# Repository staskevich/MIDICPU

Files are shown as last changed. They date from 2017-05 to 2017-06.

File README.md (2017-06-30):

MIDI CPU

copyright John Staskevich, 2017

john@codeandcopper.com

This work is licensed under a Creative Commons Attribution 4.0 International License.
http://creativecommons.org/licenses/by/4.0/

HARDWARE:

Eagle 6 board layout files and OpenOffice BOMs are included in the pcb/ folder. There is also a design for a "programming cradle" that mates the test points on the MIDI CPU with a PIC programmer for ICSP.

A public CircuitHub project is available for on-demand manufacturing:
https://circuithub.com/projects/CodeandCopper1/MIDICPU

FIRMWARE:

The code in the src/ folder can be assembled for the PIC16F887 device using Microchip's MPASM assembler. Selected firmware images are located in the hex/ folder. Firmware patches in SysEx format are in the syx/ folder.

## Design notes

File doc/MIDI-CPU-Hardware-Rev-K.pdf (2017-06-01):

Highly Liquid | MIDI CPU Hardware Rev K

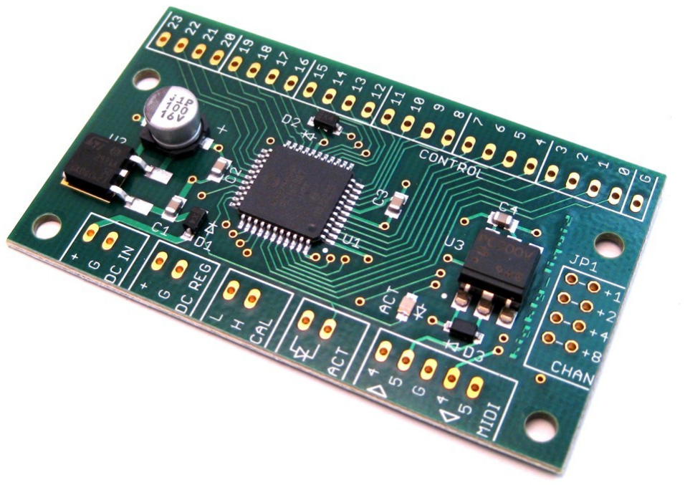
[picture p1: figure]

© 2010 Sonarcana LLC | Page 1 / 18

## MIDI CPU

## Hardware Revision K

## User Manual

### Updated 2010-09-08

Additional documentation available at: http://highlyliquid.com/support/

## Table of Contents

## 1.0 Important Safety Information

To prevent damage to the MIDI CPU and connected devices, and to prevent personal injury:
- Use an appropriate power source. Incorrect supply voltage could cause the MIDI CPU to overheat and/or cause the on-board electrolytic capacitor to explode.
- Do not connect signals which exceed the specified electrical maximums of the MIDI CPU.
- Do not exceed the specified maximum current load of MIDI CPU outputs. Overloading may damage the MIDI CPU and cause excess power consumption from the power supply.
- Take reasonable static control precautions when handling. The MIDI CPU contains ESD-sensitive parts.

## 2.0 Feature Diagram

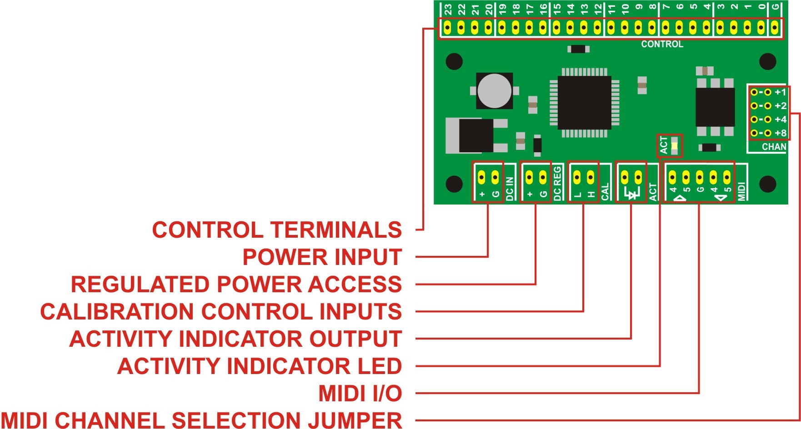
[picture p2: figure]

- Control Terminals: Switches, potentiometers, encoders, control signals or indicator LEDs are connected here. See Control Wiring.
- Power Input: DC power input. See Power Supply.
- Regulated Power Access: Output from on-board voltage regulator. See Voltage Regulation.
- Calibration Control Inputs: See MIDI CPU Firmware User Manual.
- Activity Indicator Output: Can be used to control a remote activity indicator LED. See Remote Power & Activity LED Wiring.
- Activity Indicator LED: See MIDI CPU Firmware User Manual.
- MIDI I/O: Standard MIDI IN and MIDI OUT ports. See MIDI Wiring.
- MIDI CHANNEL SELECTION JUMPER: Optionally specifies the channel for MIDI input and output. See MIDI Channel Selection Jumper.

## 3.0 Mechanical Drawing

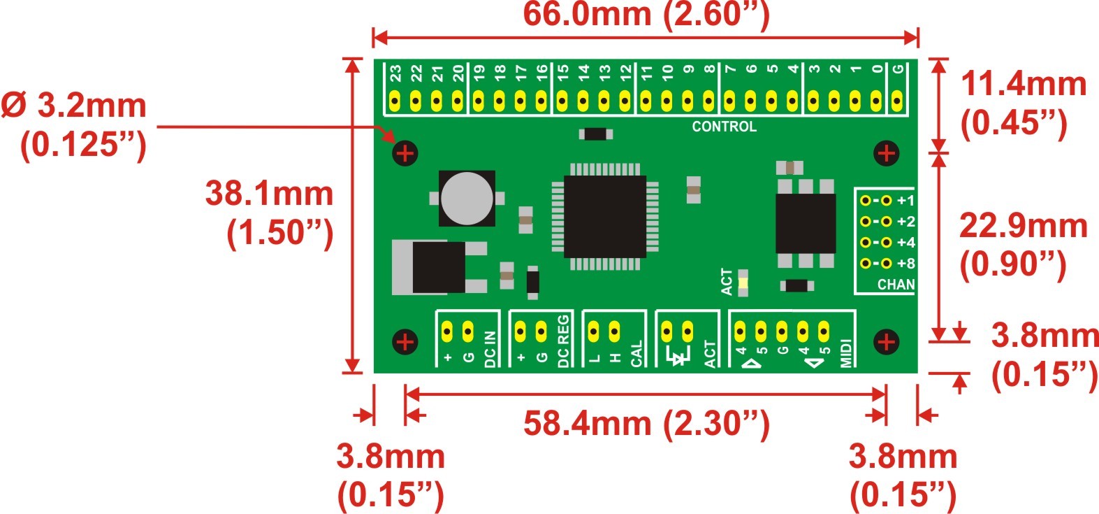
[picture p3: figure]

## 4.0 Power Supply

To operate, the MIDI CPU must be connected to a battery or other DC power supply. A “wall adapter” supply with appropriate specifications may be used. VSUPPLY refers to the output voltage of the power supply.

### 4.1 Specifications

- VSUPPLY maximum: 12VDC
- VSUPPLY minimum: 3.3VDC*
- Power supply current capacity: 150mA or greater
*Note: If VSUPPLY is less than 5.3V, the MIDI OUT signal generated by the MIDI CPU may not be strong enough to trigger some receiving devices.

### 4.2 Wiring

Wire the battery or power supply to the MIDI CPU as shown in Figure 4.1. All MIDI CPU terminals marked “G” are MIDI CPU ground.

### 4.3 Voltage Regulation

The MIDI CPU has an on-board voltage regulator. The output of the regulator powers the on-board components and is accessible via the “DC REG” terminals. Regulator output voltage (VREG) is the lesser of 5V or (VSUPPLY − 0.3V).
Figure 4.1: Power Supply Wiring

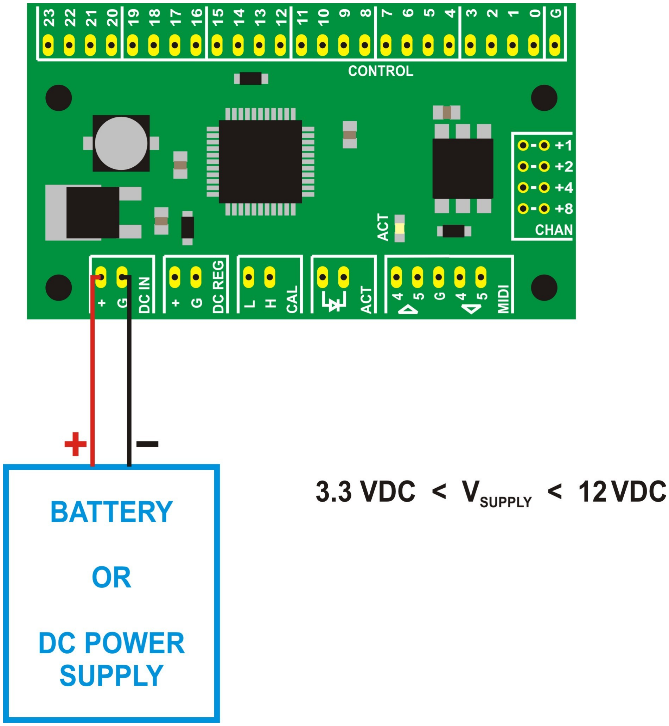
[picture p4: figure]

## 5.0 MIDI Wiring

The MIDI CPU features both a MIDI IN and MIDI OUT port. Figure 5.1 shows the typical connection to other MIDI devices.
The MIDI standard specifies a 5-position DIN connector. Figure 5.2 shows MIDI receptacle pin numbering. The MIDI signal is carried by pins 4 & 5. Pin 2 is connected to ground at the OUT or THRU side of the MIDI link, and is left unconnected at the IN side of the link. Pins 1 & 3 are unused. Connector pin numbers are marked on the MIDI CPU. See Figure 5.3.
Multiple MIDI CPU units can be chained together. For this purpose, MIDI connectors can be bypassed: the OUT port of one unit can be wired directly to the IN port of the next device in the chain. See Figure 5.4.

Figure 5.1: MIDI IN/OUT

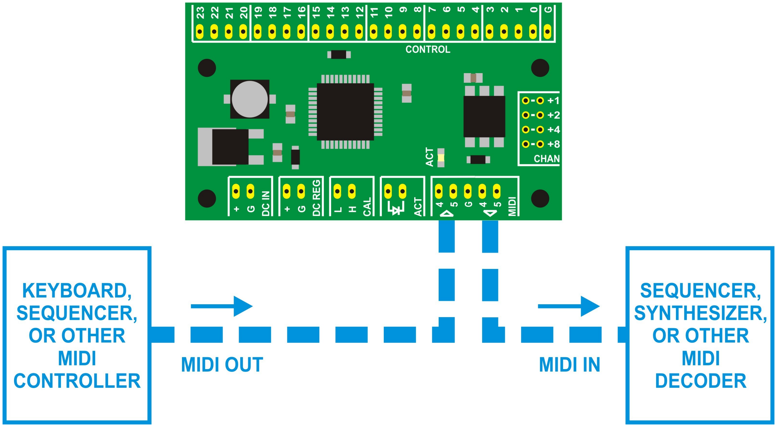
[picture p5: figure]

Figure 5.2: MIDI Receptacle Pin Numbering

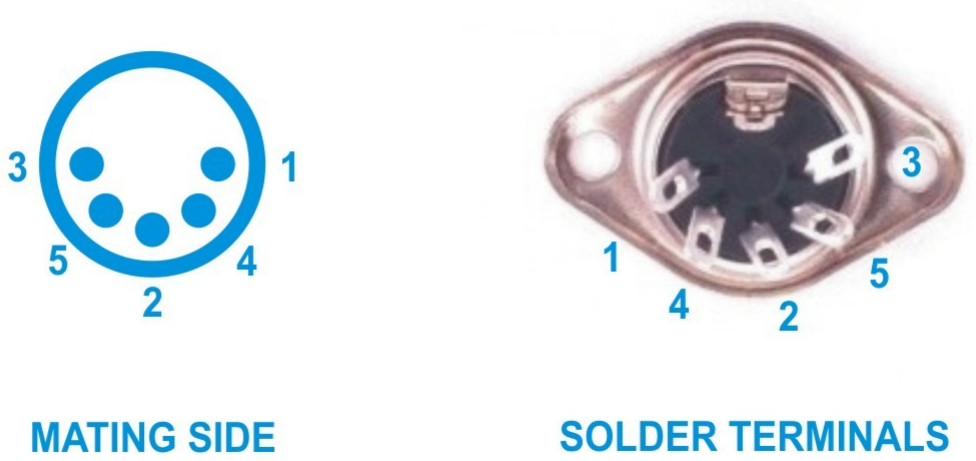
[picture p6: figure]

Figure 5.3: MIDI Receptacle Wiring

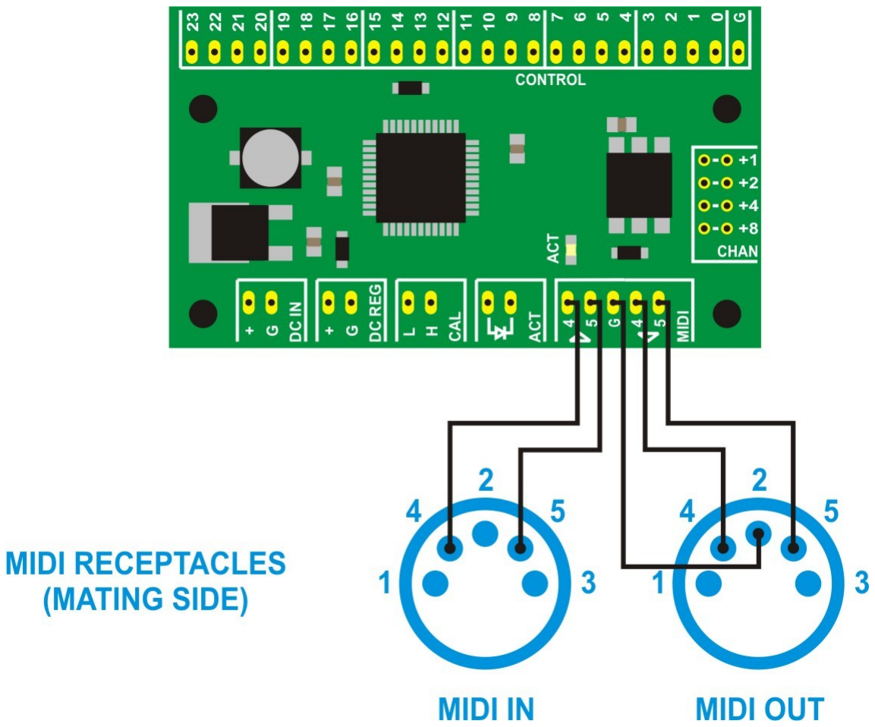
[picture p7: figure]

Figure 5.4: Multiple-Device Chain

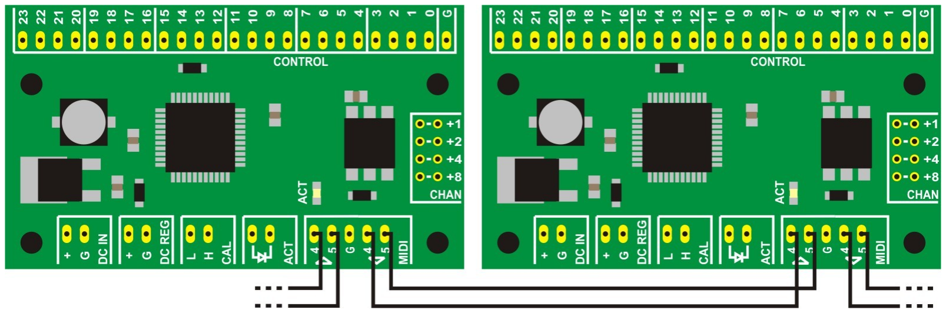
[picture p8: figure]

## 6.0 Remote Power & Activity LED Wiring

The MIDI CPU includes an on-board activity indicator LED. If desired, user-supplied power & activity LEDs can be connected. Remote activity LED wiring is via the “ACT” terminals, and can be accomplished via one of two methods.

### 6.1 Power LED Wiring

A power indicator LED can be wired to the MIDI CPU as shown in figure Figure 6.1. Select a value for RLED such that the ACT cathode terminal does not sink more than 20mA. RLED = 1.0kΩ will work with most standard-brightness LEDs.

### 6.2 Remote Activity LED Wiring, Method A

The two leads of an LED can be wired directly to the ACT terminals of the MIDI CPU. This method will work with most standard-brightness LEDs. See Figure 6.2. The ACT anode terminal is connected internally to VREG via a series 1.0kΩ current-limiting resistor.

### 6.3 Remote Activity LED Wiring, Method B

A user-supplied resistor can be used to limit the current through the remote LED. See Figure 6.3. Select a value for RLED such that the ACT cathode terminal does not sink more than 20mA.
The ACT cathode terminal is a standard logic output capable of driving external circuitry.

Figure 6.1: Power LED Wiring

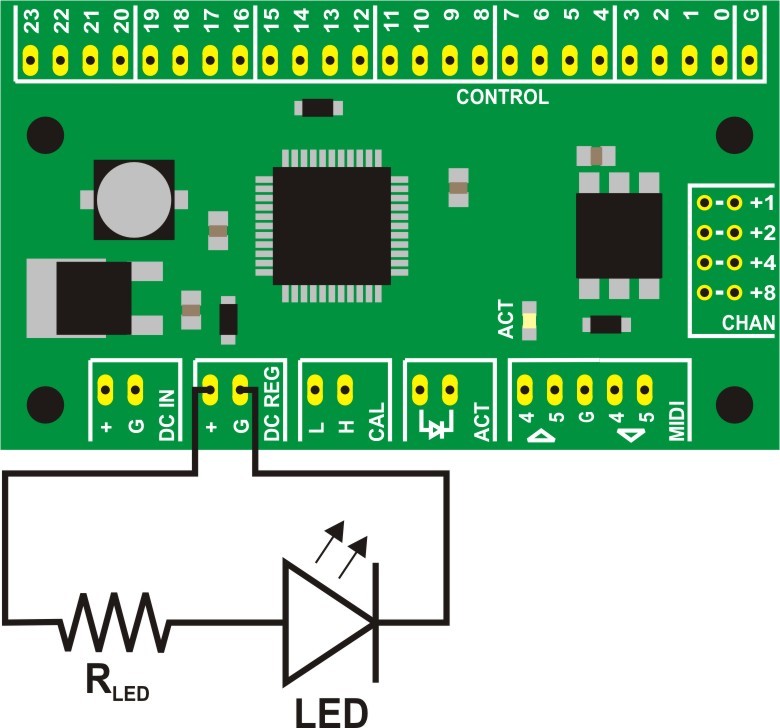
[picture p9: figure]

Figure 6.2: Remote Activity LED Wiring, Method A

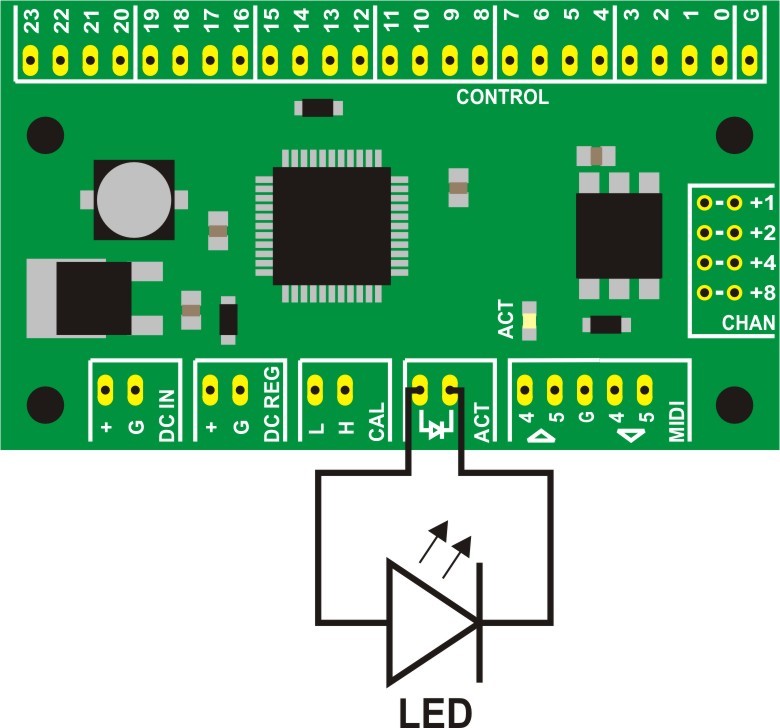
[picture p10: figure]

Figure 6.3: Remote Activity LED Wiring, Method B

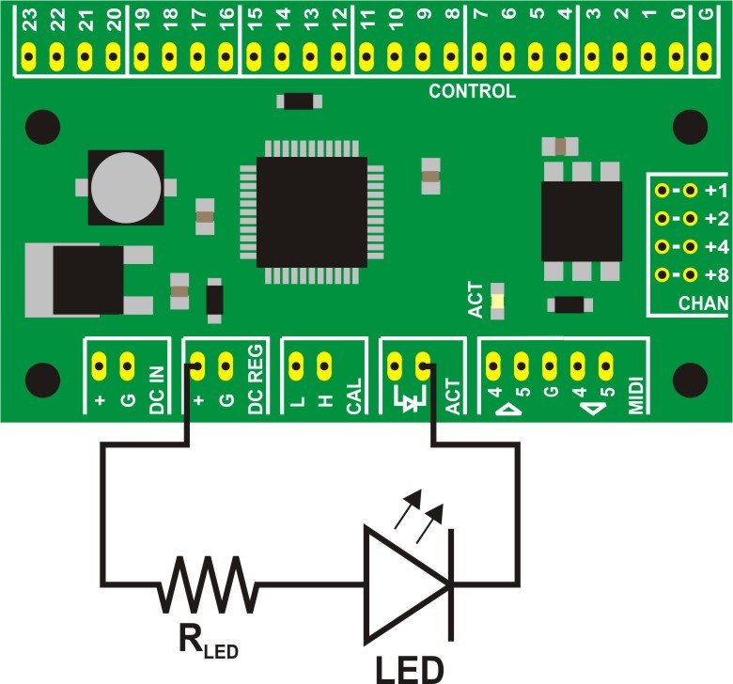
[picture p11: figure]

## 7.0 MIDI Channel Selection Jumper

The MIDI Channel Selection Jumper can be used to select the channel for MIDI input or output. See MIDI CPU Firmware User Manual for more information.
The channel selection jumper consists of 4 pairs of terminals. To specify a channel, connect zero or more terminal pairs as indicated by the dotted lines in Figure 7.1. A shorting block or piece of wire can be used.

Figure 7.1: MIDI Channel Selection Jumper Wiring

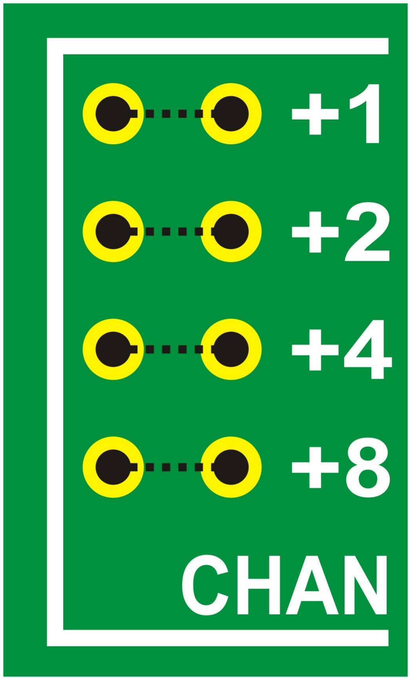
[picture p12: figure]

## 8.0 Reference Voltage Wiring

The MIDI CPU can optionally use external reference voltages for analog-to-digital conversion. See MIDI CPU Firmware User Manual for more information.
External reference voltages are connected to MIDI CPU control terminals 18 and 19 as shown in Figure
8.1. Only control terminals 18 and 19 can be used for this purpose.
When configured for reference voltage input, control terminals 18 and 19 are subject to minimum and maximum input voltages as described in Absolute Maximum Ratings.

Figure 8.1: External Reference Voltage Wiring

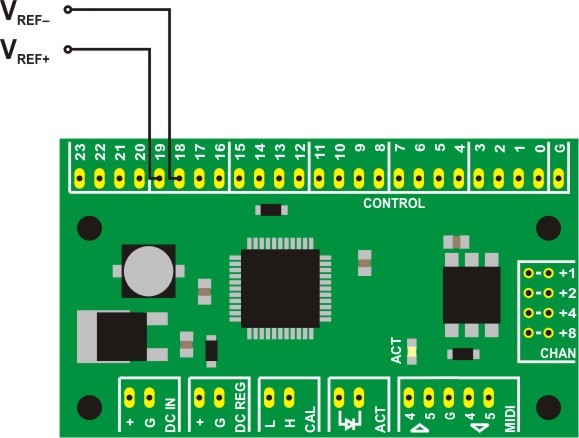
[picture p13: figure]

## 9.0 Control Wiring

Each MIDI CPU control terminal can be configured for one of up to three control functions:
- Logic Input. A logic input can be connected to a switch, switch matrix, or an externally generated logic signal. All control terminals are pulled up to VREG via internal pull-up resistors.
- Analog Input. An analog input converts an incoming analog signal to a digital value. The analog signal can be generated by a potentiometer, variable resistor, or other circuitry.
- Logic Output. A logic output generates a signal which is used together with logic inputs to monitor a switch matrix or drive an LED matrix.
Not every control terminal can perform every function. See Table 9-1. For more information about reference voltage, see Reference Voltage Wiring.

Table 9-1: Control Terminal Function Summary

Control Terminal | Logic Input | Analog Input | Logic Output | Reference Voltage
0 | √ | | √
1 | √ | | √
2 | √ | | √
3 | √ | | √
4 | √ | | √
5 | √ | | √
6 | √ | | √
7 | √ | | √
8 | √ | √ | √
9 | √ | √ | √
10 | √ | √ | √
11 | √ | √ | √
12 | √ | √ | √
13 | √ | √ | √
14 | √ | | √
15 | √ | | √
16 | √ | √ | √
17 | √ | √ | √
18 | √ | √ | √ | VREF−
19 | √ | √ | | VREF+
20 | √ | √ | √
21 | √ | √ | √
22 | √ | √ | √
23 | √ | √ | √

Different types of control wiring are described below. Any wiring scheme requires proper configuration of the MIDI CPU control terminals as described in MIDI CPU Firmware User Manual.
All terminals marked “G” are MIDI CPU ground and are internally connected to each other.

### 9.1 Basic Switch Input

Any logic input can be connected to an SPST switch. MIDI CPU ground is used as the common. See Figure 9.1. If a larger number of switch inputs are desired, a switch matrix may be used.
Because of the internal pull-up resistor connected to each control terminal, the terminal will be held VREG when the connected switch is open.

### 9.2 Switch Matrix Input

In order to conserve control terminals, or to connect a large number of input switches, a switch matrix can be employed.
A switch matrix is a d × s array of switches where d is the number of data lines, and s is the number of select lines. Data lines are connected to MIDI CPU control terminals configured as logic inputs. Select lines are connected to MIDI CPU control terminals configured as logic outputs. Unneeded switches are omitted and replaced with an open circuit.
Figure 9.2 & Figure 9.3 each show an 8 x 4 matrix with 32 total switches.
The matrix in Figure 9.2 is suitable for applications where multiple simultaneous switch closures are not expected. Certain combinations of simultaneous switch closures will cause “aliasing” to occur, and may generate unexpected results.
The matrix in Figure 9.3 includes a diode connected in series with each switch. Common small-signal diodes such as 1N914 or 1N4148 are suitable. The MIDI CPU will accurately detect all switch states, regardless of the number or combination of closed switches. Use this approach when creating a polyphonic keyboard.

### 9.3 Potentiometer Input

Potentiometers (knobs, sliders, etc.) can be connected directly to MIDI CPU analog inputs as shown in Figure 9.4 and Figure 9.5. For best results, use potentiometer values between 1.0kΩ and 10kΩ. If larger potentiometer values are used, extra circuitry is required to reduce the impedance of the analog signal.

### 9.4 Rotary Encoder Input

2-bit rotary (quadrature) encoders can be connected to MIDI CPU inputs as shown in Figure 9.6.

### 9.5 Externally Generated Signal Input

Any MIDI CPU input can be connected directly to a signal generated by external circuitry. See Figure
9.7. Any input signal must meet the specifications described in Absolute Maximum Ratings.

### 9.6 Mixed Input

Any of the above control wiring schemes can be combined. Figure 9.8 shows a MIDI CPU connected to 4 basic switch inputs, a 4 x 4 switch matrix, 8 externally generated signals, and 4 potentiometers.

### 9.7 Indicator LED Matrix Output

Indicator LED, LED 7-segment display, and LED bar graph wiring diagrams are included in MIDI CPU Firmware User Manual.

Figure 9.1: Basic Switch Input

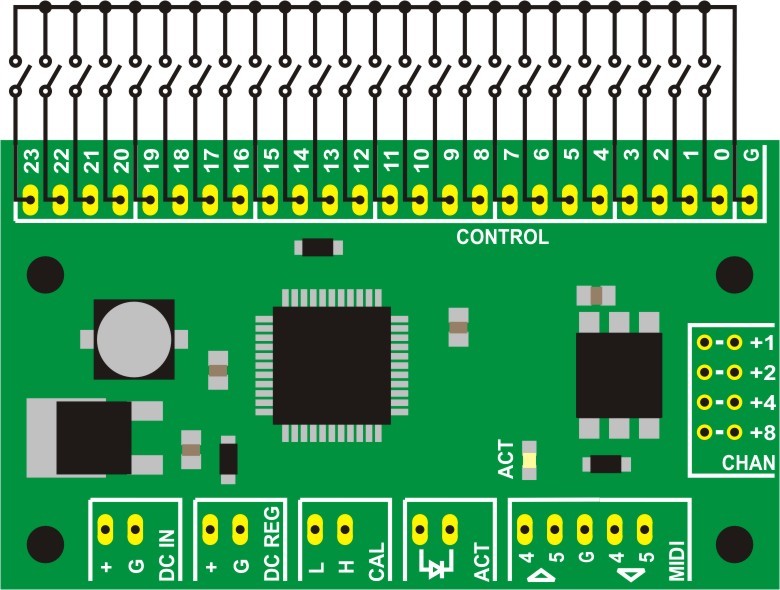
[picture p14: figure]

Figure 9.2: Switch Matrix Input, Without Diodes

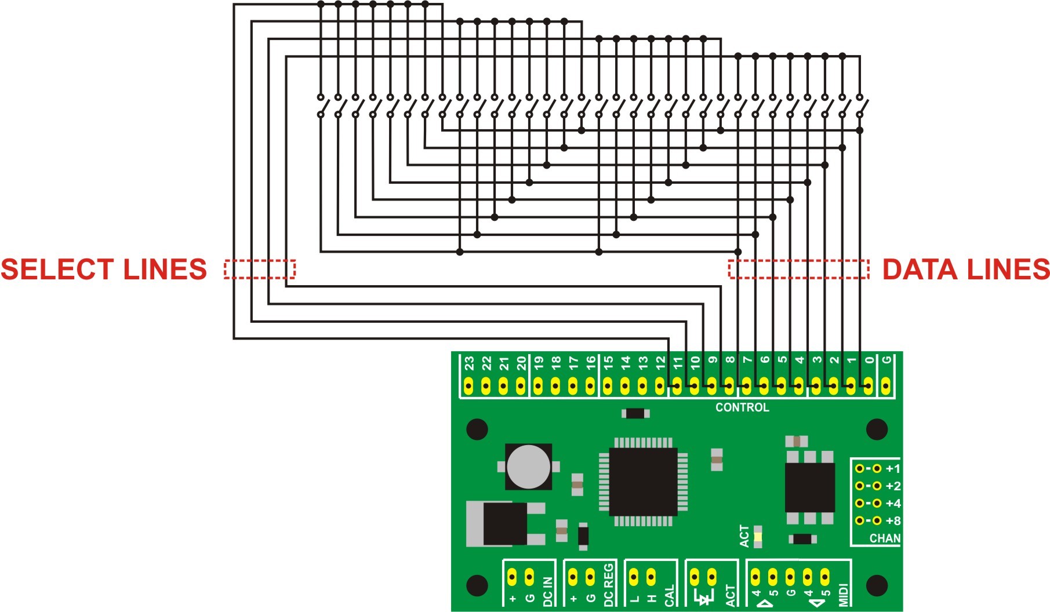
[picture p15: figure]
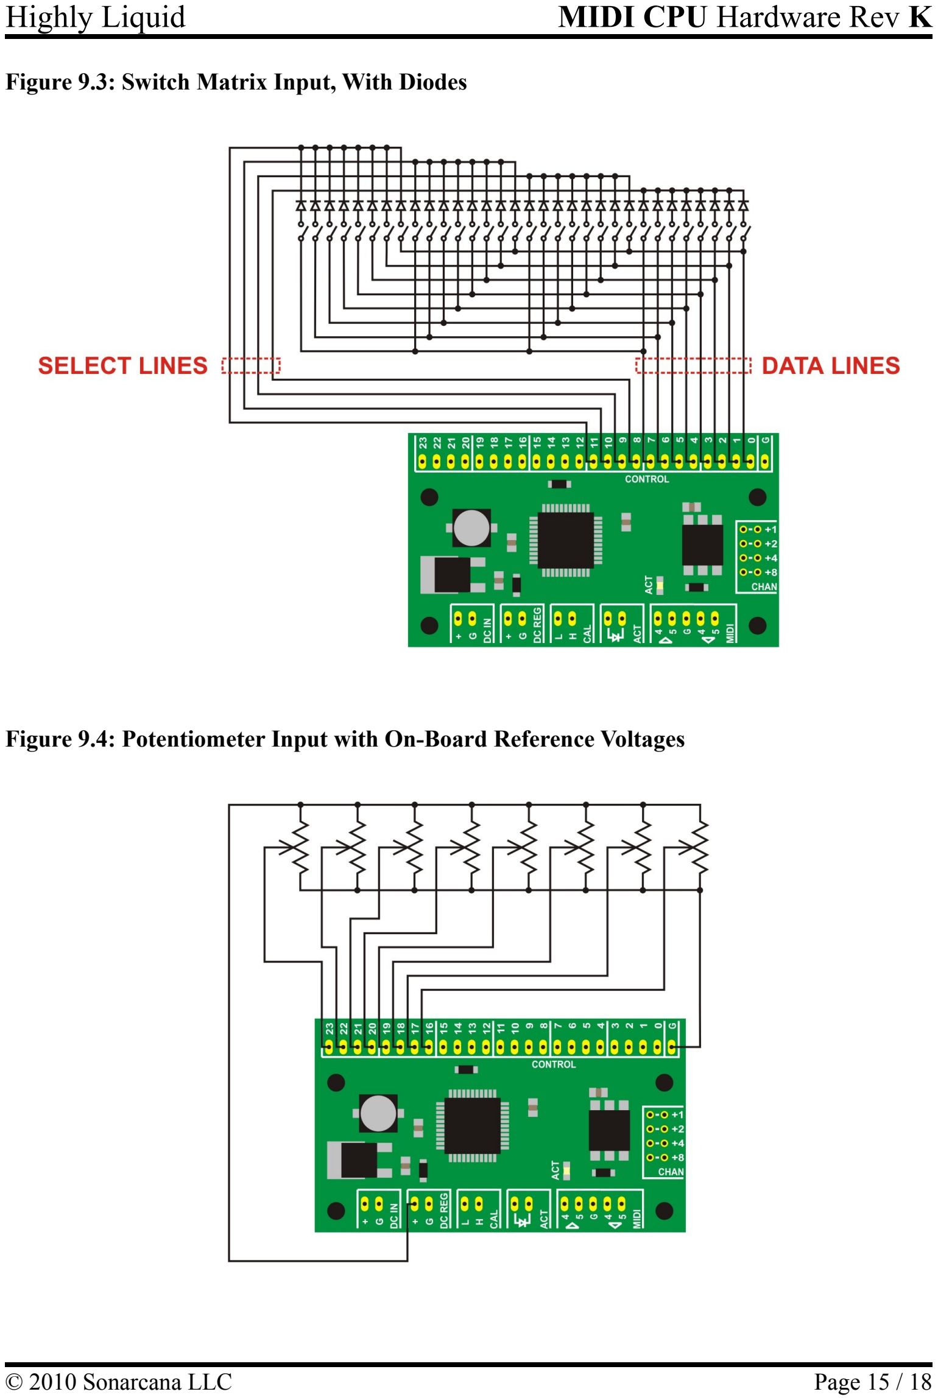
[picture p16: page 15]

Figure 9.3: Switch Matrix Input, With Diodes

Figure 9.4: Potentiometer Input with On-Board Reference Voltages

Figure 9.5: Potentiometer Input with External Reference Voltages

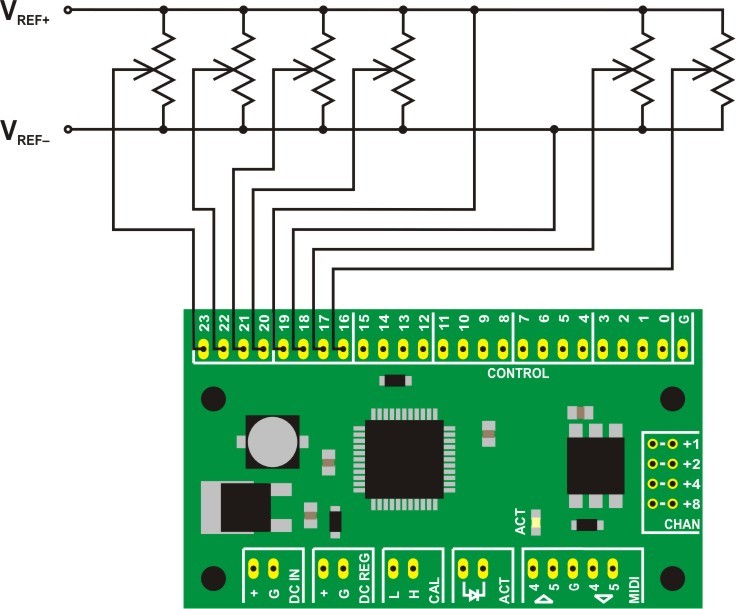
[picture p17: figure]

Figure 9.6: Rotary Encoder Input

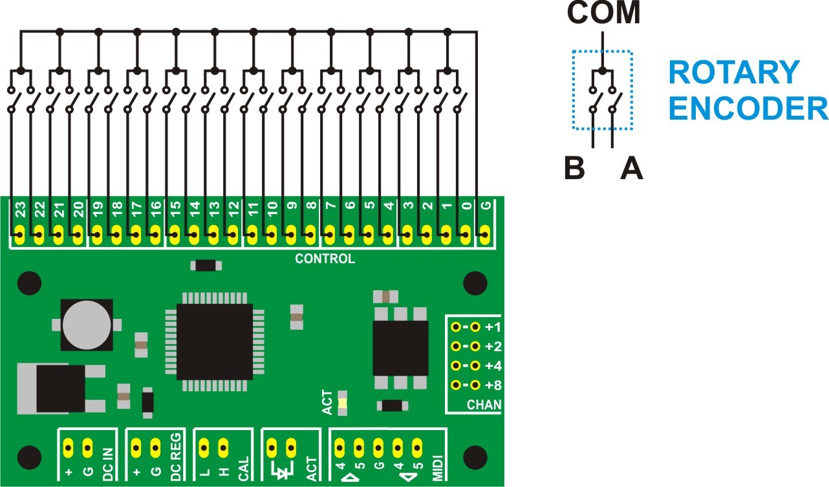
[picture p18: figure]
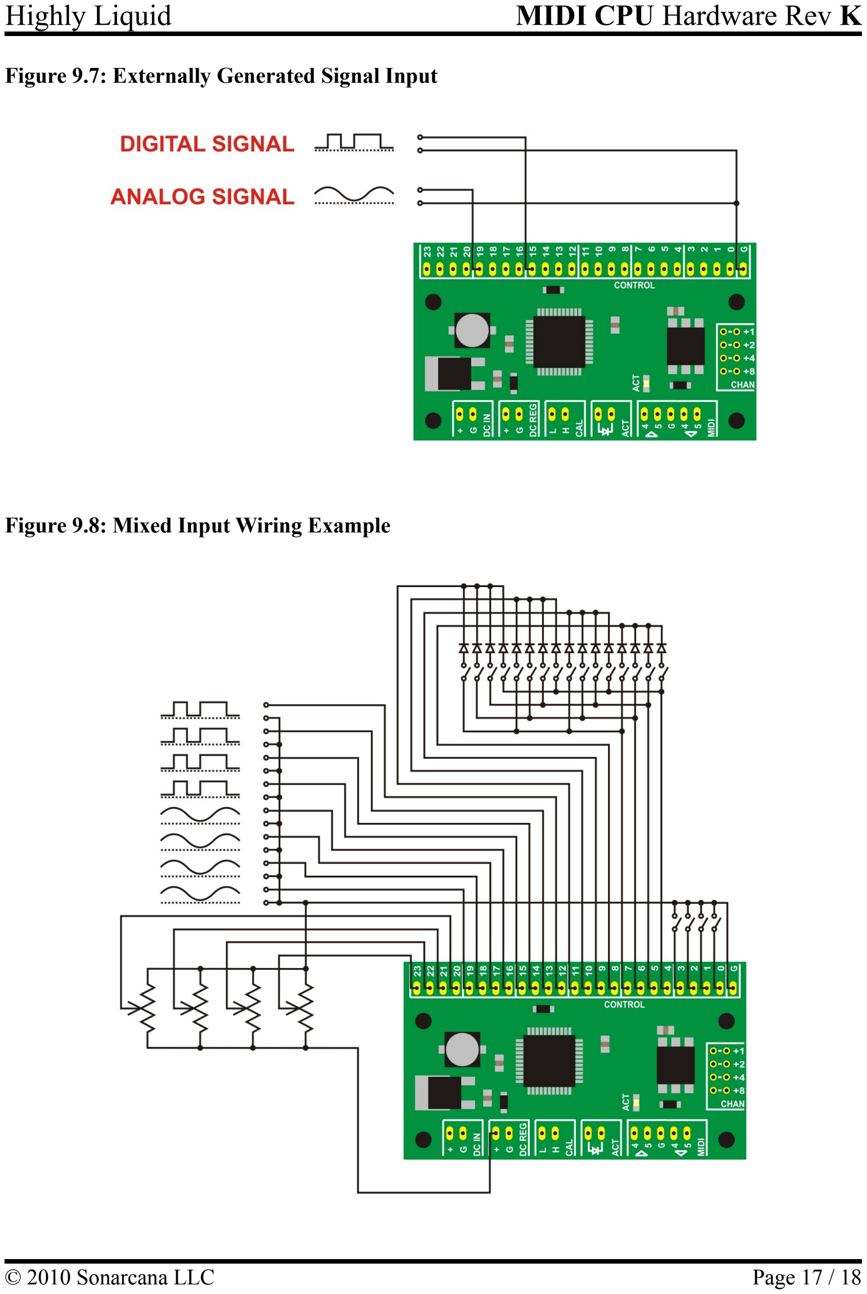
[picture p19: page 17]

Figure 9.7: Externally Generated Signal Input

Figure 9.8: Mixed Input Wiring Example

## 10.0 Electrical Specifications

### 10.1 Absolute Maximum Ratings

- Maximum control terminal input voltage: VREG (see Voltage Regulation)
- Minimum control terminal input voltage: MIDI CPU ground
- Maximum sink/source current per I/O terminal (includes “CONTROL” & “ACT” terminals): 20mA
- Maximum aggregate I/O sink/source current per MIDI CPU (includes all “CONTROL” terminals & “ACT” cathode terminal): 70mA
- Voltage regulator maximum output current (including load from on-board circuitry): 100mA

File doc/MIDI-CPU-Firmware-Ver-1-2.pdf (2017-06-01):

Highly Liquid | MIDI CPU Firmware V. 1.2
© 2013 Sonarcana LLC | Page 1 / 55

## MIDI CPU

## Firmware Version 1.2

## User Manual

### Updated 2013-05-30

Additional documentation available at: http://highlyliquid.com/support/

## Table of Contents

10.2 49-Key Keyboard Controller with Matrixed Switch Input, Velocity Knob, Program

## 1.0 Overview

Users are encouraged to read MIDI CPU Hardware User Manual before continuing with this document.

### 1.1 About The MIDI CPU

The MIDI CPU is a multipurpose MIDI input/output device. The MIDI CPU accepts input at the control terminals and MIDI IN port. Output is generated at the MIDI OUT port. Depending on configuration, certain control terminals may also generate output signals. See Theory of Operation for more information.
The MIDI CPU is configured via MIDI System Exclusive (SysEx) message. Control Terminal Configuration messages contain information related to individual control terminals. Global Configuration messages contain information related to the MIDI CPU as a whole. Configuration Examples are provided and may be adapted for specific applications.
The MIDI CPU ships with a “factory default” configuration which can be described in terms of equivalent SysEx messages. See Factory Default Configuration.
SysEx messages can also be used to examine the current MIDI CPU configuration. See Configuration Retrieval.

### 1.2 About This Document

Throughout this document, SysEx message contents are shown in hexadecimal format. Hexadecimal numbers either are described as “hex” or are followed by the 'h' suffix. Decimal format should be assumed for all other numbers.
Key to character formatting:
- Clickable links to tables and figures appear in blue.
- Clickable links to sections within the document are underscored.
- Names of specific MIDI message types generated by the MIDI CPU appear in red.
Sections of the manual that have changed significantly since the previous firmware version are highlighted in yellow.

### 1.3 Additional Resources

Instructions for using a PC to create and send SysEx messages can be found at: http://highlyliquid.com/support/library/midi-sysex.html
Support inquiries should be posted at the Highly Liquid support forums. Project examples and other information is posted at the forums:
http://forum.highlyliquid.com/

## 2.0 Theory of Operation

MIDI CPU functionality can be understood in terms of automatically repeating Tasks performed by the MIDI CPU and the resulting Data which is used to generate MIDI output.

### 2.1 Tasks

After power-up and initialization, the MIDI CPU continuously performs the following tasks: MIDI Merge, Matrix Select Signal Generation, Control Input Monitoring, MIDI Message Generation, and LED Control.

### 2.1.1 MIDI Merge

Messages received by the MIDI CPU at the MIDI IN port are echoed in real time at the MIDI OUT port, interspersed with any locally generated messages. This allows the MIDI CPU to be combined with another MIDI controller or with additional MIDI CPU units to function as a single unit with a single MIDI OUT port.
All messages received by the MIDI CPU at the MIDI IN port are echoed at the MIDI OUT port with the exception of MIDI SysEx messages and MIDI “Active Sense” messages. Active Sense messages are generated locally per the MIDI specification.
The MIDI CPU employs an efficient merge algorithm:
- Typical latency between an incoming message and the echoed output approaches the theoretical minimum of approximately 300μs.
- Merged messages and locally generated messages share the same “running status” when possible, resulting in a compact output data stream.
- Merged messages preempt locally-generated messages, allowing successful processing of a saturated data stream.

### 2.1.2 Matrix Select Signal Generation

When configured as a matrix select output, a MIDI CPU control terminal generates a matrix select logic signal. Matrix select outputs are used together with logic inputs in order to monitor a switch matrix.

### 2.1.3 Control Input Monitoring

The MIDI CPU continuously monitors each control terminal configured as an analog or logic input. Each input signal is used in up to two ways:
- The current value of the input, updated in real time, can be incorporated into outbound MIDI messages. See Data.
- A change to the input state can trigger the generation of a MIDI message.

### 2.1.4 MIDI Message Generation

The MIDI CPU generates MIDI messages based on user configuration. Message generation is triggered by changes to control terminal input. See Control Terminal Configuration and Global Configuration. Data acquired during operation can be incorporated into the generated messages. See Data.

### 2.1.5 LED Control

In addition to the built-in and optional remote Activity LED, the MIDI CPU can control multiple matrixed indicator LEDs and/or 7-segment LED displays. See MIDI CPU Hardware User Manual for wiring information. See Logic Output LED Control Modes for more details.

### 2.2 Data

The MIDI CPU has several internal memory locations called data registers which contain real-time data from control terminal inputs. Each data register contains up to a single byte (8 bits) and is identified by a unique hex address.
When the MIDI CPU generates a MIDI message, information in the message (note number & velocity, CC number & value, program number, etc) can be formed from fixed values and/or the contents of data registers.
Each data register is described below. Control Terminal Configuration and Global Configuration determine how the MIDI CPU uses the data registers.

### 2.2.1 Logic Input Data

Logic input data registers contain the current states of any control terminals configured as logic inputs. See Table 2.2.1-a. If the control terminal input state is low (0V or grounded), the corresponding data register bit is '0'. If the control terminal input state is high (VREG or unconnected), the corresponding bit is '1'. For a control terminal not configured as a logic input, the value of the corresponding logic input data register bit is unknown.

Table 2.2.1-a: Logic Input Data Registers
Register Address | Control Terminal #
Bit 7 | Bit 6 | Bit 5 | Bit 4 | Bit 3 | Bit 2 | Bit 1 | Bit 0
00h | 7 | 6 | 5 | 4 | 3 | 2 | 1 | 0
01h | 15 | 14 | 13 | 12 | 11 | 10 | 9 | 8
02h | 23 | 22 | 21 | 20 | 19 | 18 | 17 | 16

### 2.2.2 Analog Input Data

Each analog input data register contains a 7-bit representation of the input voltage on the corresponding control terminal. See Table 2.2.2-a.
For a control terminal not configured as an analog input, the corresponding analog input data register contains the value 0x7F.

Table 2.2.2-a: Analog Input Data Registers
Register Address | Control Terminal #
03h | 16
04h | 17
05h | 18
06h | 19
07h | 20
08h | 21
09h | 22
0Ah | 23
0Bh | 10
0Ch | 11
0Dh | 9
0Eh | 12
0Fh | 8
10h | 13

### 2.2.3 Multipurpose Data

Each multipurpose data register can contain a 7-bit or 8-bit value.
If a control terminal pair is configured for rotary encoder input, the 7-bit value in the corresponding data register is incremented or decremented by input activity. See Table 2.2.3-a.
If any multipurpose register is not used for encoder input, it is available for “general purpose” use: the register value can be altered via arithmetic operations and the register contents can be used to form MIDI or LED output. For bitwise operations, the register is treated as an 8-bit value. For other arithmetic operations, the register is assumed to contain a 7-bit value.
The power-up value for each register is user-configurable. See Multipurpose Data Register Initial Values.

Table 2.2.3-a: Multipurpose Data Registers: Encoder Data
Register Address | Encoder Control Terminal Pair
11h | 0,1
12h | 2,3
13h | 4,5
14h | 6,7
15h | 8,9
16h | 10,11
17h | 12,13
18h | 14,15
19h | 16,17
1Ah | 18,19
1Bh | 20,21
1Ch | 22,23

## 3.0 Control Terminal Configuration

Each MIDI CPU control terminal is associated with a control terminal configuration which is defined by one or more configuration chunks. The user sets the configuration for each control terminal via MIDI SysEx message. Configuration is retained when the MIDI CPU is disconnected from a power supply. The MIDI CPU acknowledges an incoming configuration message via the Activity Indicator LED.
New users may benefit from first reviewing the Configuration Examples.
The factory default configuration for each control terminal is described in Factory Default Configuration.

### 3.1 SysEx Message Format

Figure 3.1-1 shows the format of the Control Terminal Configuration SysEx Message. The message consists of a fixed header, a variable length body, and a fixed footer.
The body of the message consists of a layer number followed by one or more 6-byte configuration chunks, each specifying a behavior for a single MIDI CPU control terminal. The configuration of control terminals not specified in the message will remain unchanged.
When the MIDI CPU configuration is updated via a MIDI SysEx message, the device will reset, followed by the LED self-test. If no LED activity is observed, then the attempted configuration was unsuccessful.

Figure 3.1-1: Control Terminal Configuration SysEx Message Format (Hex)
Header (6 bytes) | Layer (1 byte) | Configuration Chunk (repeat as desired) | Footer (1 byte)
F0 00 01 5D 04 01 | yy | nn | tt | mm | ch | d0 | d1 | F7

### 3.1.1 Layer (yy)

Configuration layers allow a single control terminal to be associated with multiple functions.
There are 4 control terminal configuration layers. Valid values for yy are 00h, 01h, 02h, or 03h. A control terminal's layer 00h configuration will always be used to determine its behavior.
If a control terminal's layer 00h configuration specifies one of the Logic Input Trigger Modes, additional Logic Input Trigger Modes can be associated with the control terminal via configuration layers 01h, 02h, and 03h. This allows a single control terminal to simultaneously trigger multiple events upon a state change. Only Logic Input Trigger Modes may be specified for configuration layers 01h, 02h, and 03h. If a control terminal's layer 00h configuration does not specify a Logic Input Trigger Mode, configuration layers 01h, 02h, and 03h are ignored.
Use of configuration layers 01h, 02h, and 03h is optional and can vary independently by control terminal. For each control terminal, specify Logic Input: Data Only mode for configuration layers which are not needed. This is the factory default setting for all control terminals in layers 01h, 02h, and 03h. See Factory Default Configuration.

### 3.1.2 Control Terminal Identifier (nn)

Parameter nn specifies the MIDI CPU control terminal associated with the configuration chunk. Values 00h thru 17h correspond to control terminal numbers 0 thru 23.

### 3.1.3 Transition (tt)

Control terminals configured in Logic Input Trigger Modes can trigger one event on the input signal transition from high to low, and a different event on the transition from low to high. For example, a control terminal might trigger a Note On message when the input signal changes from high to low, and a Note Off message when the signal changes from low to high. For Logic Input Trigger Modes only, the value of tt associates the configuration chunk with one transition or the other. See Table 3.1.3-a.
When configuring a control terminal for any mode other than a Logic Input Trigger Mode, use the value tt = 00h.

Table 3.1.3-a: Logic Input Trigger Mode Transitions
tt | Associated Transition
00h | High to Low (Falling Edge)
01h | Low to High (Rising Edge)

### 3.1.4 Mode (mm)

Parameter mm specifies a function for the control terminal specified by nn. Valid range is 00h to 7Fh. The meanings of d0 and d1 depend on the value of mm.
Each control terminal mode falls into one of three categories:
- Logic Input: Control terminal is configured as a high-impedance digital logic input with a built-in pull-up resistor. The input state is either a binary '1' or '0' that is accessible from the Logic Input Data Register associated with the control terminal. Some modes cause a MIDI message to be generated when the input state changes.
- Analog Input: Control terminal is configured as an analog input. The input signal is continuously converted to a 7-bit digital value that is accessible from the Register associated with the control terminal. Some modes cause a MIDI message to be generated when the input state changes.
- Logic Output: Control terminal is configured as a digital logic output. The resulting signal can be used together with logic inputs to monitor a switch matrix, or can be used to drive an LED matrix.
Wiring examples for each category can be found in MIDI CPU Hardware User Manual.
Individual modes are described in sections 3.2 thru 3.5.

### 3.1.5 MIDI Channel (ch)

Some values of mm associate the control terminal with a channel-specific MIDI message. For these modes, the value of ch specifies which MIDI channel is used. ch can direct the MIDI CPU to generate messages using either a fixed channel value or the channel value specified by the MIDI Channel Selection Jumper. See Table 3.1.5-a.
The value of ch is ignored for modes which are not associated with a channel-specific MIDI message.

Table 3.1.5-a: MIDI Channel by ch Value
ch | MIDI Channel
00h | From MIDI Channel Selection Jumper
01h | 1
02h | 2
03h | 3
04h | 4
05h | 5
06h | 6
07h | 7
08h | 8
09h | 9
0Ah | 10
0Bh | 11
0Ch | 12
0Dh | 13
0Eh | 14
0Fh | 15
10h | 16

### 3.1.6 Data (d0, d1)

Depending on the value of mm, d0 and d1 can specify fixed values, data register addresses, or other information which determines the behavior of the control terminal. Details are provided in the description of each mode.

### 3.2 Logic Input Trigger Modes

Logic Input Trigger Modes configure the control terminal specified by nn as a logic input. Changes to input state may trigger MIDI output or other events.

### 3.2.1 Logic Input Trigger: Note Off

A Note Off message (status 80h) is generated when the control terminal input state changes. Note numbers are subject to MIDI Number Remapping.
Note: Note Off velocity data is ignored by most MIDI devices.
For efficient operation, do not configure the MIDI CPU to send Note Off messages. Instead, use Note On messages with a fixed velocity value of 00h.
mm | d0 Meaning | d1 Meaning
40h | Fixed note number | Fixed note velocity
41h | Data register address for note number | Fixed note velocity
42h | Fixed note number | Data register address for note velocity
43h | Data register address for note number | Data register address for note velocity

### 3.2.2 Logic Input Trigger: Note On

A Note On message is generated when the control terminal input state changes. Note numbers are subject to MIDI Number Remapping.
Note: A Note On message with a velocity of 00h is equivalent to a Note Off message.
mm | d0 Meaning | d1 Meaning
44h | Fixed note number | Fixed note velocity
45h | Data register address for note number | Fixed note velocity
46h | Fixed note number | Data register address for note velocity
47h | Data register address for note number | Data register address for note velocity

### 3.2.3 Logic Input Trigger: Aftertouch

An Aftertouch message is generated when the control terminal input state changes. Note numbers are subject to MIDI Number Remapping.

mm | d0 Meaning | d1 Meaning
48h | Fixed note number | Fixed pressure value
49h | Data register address for note number | Fixed pressure value
4Ah | Fixed note number | Data register address for pressure value
4Bh | Data register address for note number | Data register address for pressure value

### 3.2.4 Logic Input Trigger: Control Change (CC)

A Control Change (CC) message is generated when the control terminal input state changes.

mm | d0 Meaning | d1 Meaning
4Ch | Fixed CC number | Fixed CC value
4Dh | Data register address for CC number | Fixed CC value
4Eh | Fixed CC number | Data register address for CC value
4Fh | Data register address for CC number | Data register address for CC value

### 3.2.5 Logic Input Trigger: Control Change (CC) Toggle

A Control Change (CC) message is generated when the control terminal input state changes. The CC value alternates between the global CC “on” value and the global CC “off” value. See Control Change (CC) “On/Off” Values.

mm | d0 Meaning | d1 Meaning
56h | Fixed CC number | Ignored
57h | Data register address for CC number | Ignored

### 3.2.6 Logic Input Trigger: Program Change

A Program Change message is generated when the control terminal input state changes.
For modes 52h and 53h, the program number is the result of adding the values specified by d0 and d1.
mm | d0 Meaning | d1 Meaning
50h | Fixed program number | Ignored
51h | Data register address for program number | Ignored
52h | Fixed program number | Data register address for program number addend
53h | Data register address for program number | Data register address for program number addend

### 3.2.7 Logic Input Trigger: Channel Pressure

a Channel Pressure message is generated when the control terminal input state changes.

mm | d0 Meaning | d1 Meaning
54h | Fixed pressure value | Ignored
55h | Data register address for pressure value | Ignored

### 3.2.8 Logic Input Trigger: Pitch Wheel

A Pitch Wheel message is generated when the control terminal input state changes.
Pitch Wheel messages contain 14 bits of position data. The high-order bits (bits 13 thru 7) have a large impact on pitch change and the low-order bits (bits 6 thru 0) have a small impact.
For mm = 5Ah, it is recommended that d0 = 00h.
mm | d0 Meaning | d1 Meaning
58h | Fixed value for position bits 6-0 | Fixed value for position bits 13-7
59h | Data register address for position bits 6-0 | Fixed value for position bits 13-7
5Ah | Fixed value for position bits 6-0 | Data register address for position bits 13-7
5Bh | Data register address for position bits 6-0 | Data register address for position bits 13-7

### 3.2.9 Logic Input Trigger: System Exclusive (SysEx)

An arbitrary SysEx message is generated when the control terminal input state changes.
The generated SysEx message consists of the standard “SysEx Begin” status byte (F0h) followed by data from the SysEx Data Buffer as specified by d0 & d1 and closed with the standard “SysEx End” status byte (F7h).
mm | d0 Meaning | d1 Meaning
5Ch | SysEx buffer starting address | Data length (bytes)

### 3.2.10 Logic Input Trigger: MIDI Start

A MIDI Start message is generated when the control terminal input state changes.

mm | d0 Meaning | d1 Meaning
64h | Ignored | Ignored

### 3.2.11 Logic Input Trigger: MIDI Stop

A MIDI Stop message is generated when the control terminal input state changes.

mm | d0 Meaning | d1 Meaning
65h | Ignored | Ignored

### 3.2.12 Logic Input Trigger: MIDI Start / MIDI Stop Toggle

Alternating MIDI Start and MIDI Stop messages are generated when the control terminal input state changes.

mm | d0 Meaning | d1 Meaning
66h | Ignored | Ignored

### 3.2.13 Logic Input Trigger: MIDI Clock

A MIDI Clock message is generated when the control terminal input state changes.

mm | d0 Meaning | d1 Meaning
67h | Ignored | Ignored

### 3.2.14 Logic Input Trigger: Analog Continuous Note Start

If the control terminal specified by d0 is configured in Analog Input: Continuous Note mode, note generation begins.

mm | d0 Meaning | d1 Meaning
68h | Analog Input Control Terminal # | Ignored

### 3.2.15 Logic Input Trigger: Analog Continuous Note Stop

If the control terminal specified by d0 is configured in Analog Input: Continuous Note mode, note generation halts.

mm | d0 Meaning | d1 Meaning
69h | Analog Input Control Terminal # | Ignored

### 3.2.16 Logic Input Trigger: Encoder Continuous Note Start

If the control terminal pair specified by d0 is configured in Encoder Input: Continuous Note mode, note generation begins. For d0, use the lower of the two control terminal numbers in the pair.

mm | d0 Meaning | d1 Meaning
6Ah | Encoder Input Control Terminal # | Ignored

### 3.2.17 Logic Input Trigger: Encoder Continuous Note Stop

If the control terminal specified by d0 is configured in Encoder Input: Continuous Note mode, note generation halts. For d0, use the lower of the two control terminal numbers in the pair.

mm | d0 Meaning | d1 Meaning
6Bh | Encoder Input Control Terminal # | Ignored

### 3.2.18 Logic Input Trigger: MIDI Reset

A MIDI Reset message is generated when the control terminal input state changes.

mm | d0 Meaning | d1 Meaning
7Eh | Ignored | Ignored

### 3.2.19 Logic Input Trigger: Data Register: Increment

The register specified by d0 is incremented by the amount d1 when the control terminal input state changes. No MIDI event is triggered.

mm | d0 Meaning | d1 Meaning
70h | Data Register Address | Increment Value

### 3.2.20 Logic Input Trigger: Data Register: Decrement

The register specified by d0 is decremented by the amount d1 when the control terminal input state changes. No MIDI event is triggered.

mm | d0 Meaning | d1 Meaning
71h | Data Register Address | Decrement Value

### 3.2.21 Logic Input Trigger: Data Register: Store Value

The value specified by d1 is stored in the register specified by d0 when the control terminal input state changes. No MIDI event is triggered.

mm | d0 Meaning | d1 Meaning
74h | Data Register Address | Value

### 3.2.22 Logic Input Trigger: Data Register: Clear / Set / Toggle Bit

A bit in the register specified by d0 is cleared, set or toggled when the control terminal input state changes. No MIDI event is triggered.
The value of d1 specifies both the bit to be altered, and whether the bit should be cleared, set, or toggled. Values 00h-07h cause the bit numbered d1 to be cleared. Values 08h-0Fh cause the bit numbered (d1-8) to be set. Values 10h-17h cause the bit numbered (d1-16) to be toggled.
mm | d0 Meaning | d1 Meaning
76h | Data Register Address | Clear / Set / Toggle; Bit #

### 3.2.23 Logic Input: Data Only

The following mode configures the control terminal as a logic input. The input state is available as Logic Input Data, but no event is triggered by state changes.

mm | d0 Meaning | d1 Meaning
7Fh | Ignored | Ignored

### 3.3 Logic Input Rotary Encoder Modes

Logic Input Rotary Encoder Modes configure the control terminal specified by nn as a logic input. For proper operation, both control terminals in an encoder input pair must be given the same configuration. See Table 2.2.3-a for a list of control terminal encoder input pairs. When the attached rotary encoder is adjusted, the value in the control terminal pair's corresponding data register is incremented or decremented.
The initial value upon power-up for each data register is user configurable. See Multipurpose Data Register Initial Values.

### 3.3.1 Encoder Input: Continuous Note

A continuous stream of MIDI notes is generated. The encoder data register for the control terminal determines the note number of the current note. Must be used in conjunction with modes Logic Input Trigger: Encoder Continuous Note Start and Logic Input Trigger: Encoder Continuous Note Stop.
If note generation has begun, input from the rotary encoder simultaneously causes the previous MIDI note to be canceled with a Note Off message and a new note to be initiated with a Note On message. Note numbers are subject to MIDI Number Remapping.
mm | d0 Meaning | d1 Meaning
10h | Ignored | Fixed note velocity
11h | Ignored | Data register address for note velocity

### 3.3.2 Encoder Input: Control Change (CC)

A Control Change message is generated when input is received from the rotary encoder.

mm | d0 Meaning | d1 Meaning
14h | Fixed CC number | Data register address for CC value
15h | Data register address for CC number | Data register address for CC value

### 3.3.3 Encoder Input: Program Change

A Program Change message is generated when input is received from the rotary encoder.

mm | d0 Meaning | d1 Meaning
16h | Data register address for program number | Ignored

### 3.3.4 Encoder Input: Channel Pressure

A Channel Pressure message is generated when input is received from the rotary encoder.

mm | d0 Meaning | d1 Meaning
17h | Data register address for pressure value | Ignored

### 3.3.5 Encoder Input: Matrix Note Velocity

Input from the encoder sets the note velocity value for any Note On messages associated with control terminals operating in a Matrix Select Mode.
Control terminal input overrides the global Matrix Note Velocity setting.
mm | d0 Meaning | d1 Meaning
1Ah | Ignored | Ignored

### 3.3.6 Encoder Input: Control Change (CC) “On” Value

Input from the encoder sets the global CC “On” value.
Control terminal input overrides the Control Change (CC) “On/Off” Values setting.
mm | d0 Meaning | d1 Meaning
1Bh | Ignored | Ignored

### 3.3.7 Encoder Input: Control Change (CC) “Off” Value

Input from the encoder sets the global CC “Off” value.
Control terminal input overrides the Control Change (CC) “On/Off” Values setting.
mm | d0 Meaning | d1 Meaning
1Ch | Ignored | Ignored

### 3.3.8 Encoder Input: Data Only

When input from the rotary encoder is received, the value in the corresponding data register is adjusted, but no MIDI message is generated.

mm | d0 Meaning | d1 Meaning
1Fh | Ignored | Ignored

### 3.4 Analog Input Modes

Analog Input Modes configure the control terminal specified by nn as an analog input. Changes to input state may trigger MIDI output or other events.
Only certain control terminals can be configured as analog inputs – see MIDI CPU Hardware User Manual.

### 3.4.1 Analog Input: Continuous Note

A continuous stream of MIDI notes is generated. The analog data register for the control terminal determines the note number of the current note. Must be used in conjunction with modes Logic Input Trigger: Analog Continuous Note Start and Logic Input Trigger: Analog Continuous Note Stop.
If note generation has begun, change to the analog input simultaneously causes the previous MIDI note to be canceled with a Note Off message and a new note to be initiated with a Note On message. Note numbers are subject to MIDI Number Remapping.
mm | d0 Meaning | d1 Meaning
00h | Ignored | Fixed note velocity
01h | Ignored | Data register address for velocity

### 3.4.2 Analog Input: Aftertouch

Change to the analog input signal causes an Aftertouch message to be generated. Note numbers are subject to MIDI Number Remapping.

mm | d0 Meaning | d1 Meaning
02h | Fixed note number | Data register address for pressure value
03h | Data register address for note number | Data register address for pressure value

### 3.4.3 Analog Input: Control Change (CC)

Whenever the analog input signal changes, a Control Change message is generated.

mm | d0 Meaning | d1 Meaning
04h | Fixed CC number | Data register address for CC value
05h | Data register address for CC number | Data register address for CC value

### 3.4.4 Analog Input: Program Change

Whenever the analog input signal changes, a Program Change message is generated.

mm | d0 Meaning | d1 Meaning
06h | Data register address for program number | Ignored

### 3.4.5 Analog Input: Channel Pressure

Whenever the analog input signal changes, a Channel Pressure message is generated.

mm | d0 Meaning | d1 Meaning
07h | Data register address for pressure number | Ignored

### 3.4.6 Analog Input: Pitch Wheel

Whenever the analog input signal changes, a Pitch Wheel message is generated.

mm | d0 Meaning | d1 Meaning
08h | Ignored | Data register address for position value

### 3.4.7 Analog Input: Matrix Note Velocity

The analog input signal sets the note velocity value for any Note On messages associated with control terminals operating in a Matrix Select Mode.
Control terminal input overrides the global Matrix Note Velocity setting.
mm | d0 Meaning | d1 Meaning
0Ah | Ignored | Ignored

### 3.4.8 Analog Input: Control Change (CC) “On” Value

The analog input signal sets the global CC “On” value.
Control terminal input overrides the Control Change (CC) “On/Off” Values setting.
mm | d0 Meaning | d1 Meaning
0Bh | Ignored | Ignored

### 3.4.9 Analog Input: Control Change (CC) “Off” Value

The analog input signal sets the global CC “Off” value.
Control terminal input overrides the Control Change (CC) “On/Off” Values setting.
mm | d0 Meaning | d1 Meaning
0Ch | Ignored | Ignored

### 3.4.10 Analog Input: Data Only

Analog input is converted to a 7-bit value and stored in the analog data register corresponding to the control terminal, but no MIDI message is generated.

mm | d0 Meaning | d1 Meaning
0Fh | Ignored | Ignored

### 3.5 Logic Output Matrix Select Modes

A Logic Output Matrix Select Mode causes the associated control terminal to periodically generate a matrix select output signal, allowing the MIDI CPU to monitor the states of switches in a switch matrix. Only certain control terminals can be configured as logic outputs – see MIDI CPU Hardware User Manual.
When a control terminal is configured in a Logic Output Matrix Select Mode, the following “select cycle” will repeat continuously:
1. Control terminal begins in a high-impedance (input) state.
2. A select pulse (0V output) from the control terminal is initiated.
3. The MIDI CPU takes a “snapshot” of the switch state data register associated with the mode.
4. Control terminal returns to high-impedance (input) state.
5. The Matrix Data Bitmask is applied to the snapshot.
6. MIDI messages are generated according to any changed switch states.
7. The output remains inactive (high-impedance) while select pulses are generated by other matrix select control terminals.
8. Cycle repeats with step 1.
The frequency of the select cycle (or “matrix sampling rate”) varies depending on MIDI CPU configuration and input activity. The typical rate approaches 1,000 select cycles per second.

### 3.5.1 Matrix Select: Note On / Note Off

When a switch state changes from high to low, a Note On message is generated. When a switch state changes from low to high, a Note Off message is generated.
The note number for each switch is determined by the value of d0. Switch state data register bit 0 generates messages with note number d0, bit 1 generates messages with note number d0 + 1, bit 2 generates messages with note number d0 + 2, etc. Note numbers are subject to MIDI Number Remapping.
Note velocity is determined by either global configuration variable, analog input, or encoder input. See Matrix Note Velocity, Analog Input: Matrix Note Velocity, or Encoder Input: Matrix Note Velocity.
mm | Switch State Data Register | d0 Meaning | d1 Meaning
2Ch | 00h | Note number for data bit 0 | Matrix Data Bitmask
2Dh | 01h | Note number for data bit 0 | Matrix Data Bitmask
2Eh | 02h | Note number for data bit 0 | Matrix Data Bitmask

### 3.5.2 Matrix Select: Note Toggle

Alternating Note On and Note Off messages are generated when a switch state changes from high to low. The note number for each switch is determined by the value of d0. Switch state data register bit 0 generates messages with note number d0, bit 1 generates messages with note number d0 + 1, bit 2 generates messages with note number d0 + 2, etc. Note numbers are subject to MIDI Number Remapping.
Note velocity is determined by either global configuration variable, analog input, or encoder input. See Matrix Note Velocity, Analog Input: Matrix Note Velocity, or Encoder Input: Matrix Note Velocity.
mm | Switch State Data Register | d0 Meaning | d1 Meaning
30h | 00h | Note number for data bit 0 | Matrix Data Bitmask
31h | 01h | Note number for data bit 0 | Matrix Data Bitmask
32h | 02h | Note number for data bit 0 | Matrix Data Bitmask

### 3.5.3 Matrix Select: Control Change (CC) On/Off

When a switch state changes, a Control Change message is generated.
The CC number for each switch is determined by the value of d0. Switch state data register bit 0 generates messages with CC number d0, bit 1 generates messages with CC number d0 + 1, bit 2 generates messages with CC number d0 + 2, etc.
When a switch state changes from high to low, the CC “on” value is used. When a switch state changes state from low to high, the CC “off” value is used. CC on/off values are determined by global configuration variables. See Control Change (CC) “On/Off” Values.
mm | Switch State Data Register | d0 Meaning | d1 Meaning
34h | 00h | CC number for data bit 0 | Matrix Data Bitmask
35h | 01h | CC number for data bit 0 | Matrix Data Bitmask
36h | 02h | CC number for data bit 0 | Matrix Data Bitmask

### 3.5.4 Matrix Select: Control Change (CC) Toggle

When a switch state changes from high to low, a Control Change message is generated.
CC number for each switch is determined by the value of d0. Switch state data register bit 0 generates messages with CC number d0, bit 1 generates messages with CC number d0 + 1, bit 2 generates messages with CC number d0 + 2, etc.
The CC value alternates between the global CC “on” value and the global CC “off” value. See Control Change (CC) “On/Off” Values.
mm | Switch State Data Register | d0 Meaning | d1 Meaning
38h | 00h | CC number for data bit 0 | Matrix Data Bitmask
39h | 01h | CC number for data bit 0 | Matrix Data Bitmask
3Ah | 02h | CC number for data bit 0 | Matrix Data Bitmask

### 3.5.5 Matrix Select: Program Change

When a switch state changes from high to low, a Program Change message is generated.
The program number for each switch is determined by the value of d0. Switch state data register bit 0 generates messages with program number d0, bit 1 generates messages with program number d0 + 1, bit 2 generates messages with program number d0 + 2, etc.
mm | Switch State Data Register | d0 Meaning | d1 Meaning
3Ch | 00h | Program number for data bit 0 | Matrix Data Bitmask
3Dh | 01h | Program number for data bit 0 | Matrix Data Bitmask
3Eh | 02h | Program number for data bit 0 | Matrix Data Bitmask

### 3.5.6 Matrix Data Bitmask

Logic Output Matrix Select Modes employ a bitmask specified by the value of d1.
When processing data from the switch state data register, the MIDI CPU can ignore certain data bits as directed by the bitmask. Bits with a bitmask value of '0' are ignored. Values for d1 and the corresponding bitmasks are shown in Table 3.5.6-a.
When a switch matrix does not employ all 8 control terminals associated with a data register, the correct bitmask prevents the unused control terminals from interfering with matrix monitoring. The unused control terminals can therefore be configured for other purposes.

Table 3.5.6-a: Matrix Data Bitmasks
d1 | Data Bitmask
Bit 7 | Bit 6 | Bit 5 | Bit 4 | Bit 3 | Bit 2 | Bit 1 | Bit 0
00h | 1 | 1 | 1 | 1 | 1 | 1 | 1 | 1
01h | 1 | 1 | 1 | 1 | 1 | 1 | 1 | 0
02h | 1 | 1 | 1 | 1 | 1 | 1 | 0 | 0
03h | 1 | 1 | 1 | 1 | 1 | 0 | 0 | 0
04h | 1 | 1 | 1 | 1 | 0 | 0 | 0 | 0
05h | 1 | 1 | 1 | 0 | 0 | 0 | 0 | 0
06h | 1 | 1 | 0 | 0 | 0 | 0 | 0 | 0
07h | 1 | 0 | 0 | 0 | 0 | 0 | 0 | 0
08h | 0 | 1 | 1 | 1 | 1 | 1 | 1 | 1
09h | 0 | 0 | 1 | 1 | 1 | 1 | 1 | 1
0Ah | 0 | 0 | 0 | 1 | 1 | 1 | 1 | 1
0Bh | 0 | 0 | 0 | 0 | 1 | 1 | 1 | 1
0Ch | 0 | 0 | 0 | 0 | 0 | 1 | 1 | 1
0Dh | 0 | 0 | 0 | 0 | 0 | 0 | 1 | 1
0Eh | 0 | 0 | 0 | 0 | 0 | 0 | 0 | 1

### 3.6 Logic Output LED Control Modes

The following modes configure the control terminal specified by nn for logic output.
The MIDI CPU can control up to 64 LEDs arranged in an 8x8 matrix. The matrix can be comprised of a mixture of individual indicator LEDs, 7-segment numerical displays, and 8-segment “bar graph” displays. LED control functionality requires that at least one control terminal (0-7) be configured for LED Data Output and at least one control terminal (8-15) be configured for LED Common Output.
Control terminals configured for LED control output are subject the electrical limitations described in MIDI CPU Hardware User Manual.

### 3.6.1 LED Data Output

The control terminal generates a control signal that drives an attached LED matrix. Must be used in conjunction with control terminals configured for LED Common Output.
Note: Only control terminals 0-7 can be configured for LED data output. If one or more control terminals are configured for LED data output, control terminals 0-7 cannot be configured as matrix select outputs.
mm | d0 Meaning | d1 Meaning
2Bh | Ignored | Ignored

### 3.6.2 LED Common Output

The control terminal generates a “common” control signal for up to 8 LEDs arranged in either a common-anode or common-cathode configuration. The data signal for each LED is automatically generated by control terminals configured for LED Data Output.
The contents of the data register at address d1 are formatted as specified by d0.
Note: Only control terminals 8-15 can be configured for LED common output.
mm | d0 Meaning | d1 Meaning
2Ah | LED Output Format | LED State Register

### 3.6.3 LED Output Format

LED common output mode employs an output format specified by the value of d0. The output format encodes all of the following:
- The polarity of the attached LED array (“common anode” or “common cathode”)
- Whether or not the common signal is externally inverted
- The display type for the value in the LED state register
When a common anode format is used, the control terminal drives the anodes of up to 8 LEDs. Each LED cathode must be connected to a different MIDI CPU control terminal configured for LED Data Output.

When a common cathode format is used, the control terminal drives the cathodes of up to 8 LEDs. Each LED anode must be connected to a different MIDI CPU control terminal configured for LED Data Output.
Because of the electrical limitations of the MIDI CPU, LED common output signals may be externally buffered by the user. Inverted common output formats are available for applications where “inverting” buffering methods are employed.
The following LED display types are available:
Bit Indication: The state of each LED reflects the corresponding bit in the LED state register. 1 = on; 0 = off.
7-Segment Display (00h = “0”): The LED state register value is interpreted as an integer. Use these formats to display an unsigned value between 0 and 127.
7-Segment Display (40h = “0”): The LED state register value is interpreted as an integer. Use these formats to display a signed value between -64 and 63.
Bar Graph: The LED state register value is interpreted as an integer. When the state register value is 0, only LED0 is illuminated. Each increase of 16 to the state register value causes the illumination of an additional LED.
The LED state summary for each display type is shown in Table 3.6.3-a. For any group of LEDs sharing the same LED common output, LED0-LED7 correspond to LED data output from control terminals 0-7. Figure 3.6.3-1 shows the standard segment labels for a 7-segment digit.
Output formats and corresponding d0 values are shown in Table 3.6.3-b.

Table 3.6.3-a: LED State Summary by Display Type

Display Type | LED State
LED7 | LED6 | LED5 | LED4 | LED3 | LED2 | LED1 | LED0
Bit Indication | Bit 7 | Bit 6 | Bit 5 | Bit 4 | Bit 3 | Bit 2 | Bit 1 | Bit 0
7-Segment | Off | G | F | E | D | C | B | A
Bar Graph | ≥ 112 | ≥ 96 | ≥ 80 | ≥ 64 | ≥ 48 | ≥ 32 | ≥ 16 | On

Figure 3.6.3-1: 7-Segment Display Segment Labels

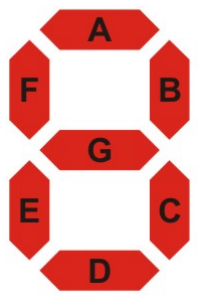
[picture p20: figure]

Table 3.6.3-b: LED Common Output Formats

d0 | Common | Display Type
00h | Anode, Non-Inverted | Bit Indication
01h | Anode, Inverted | Bit Indication
02h | Cathode, Non-Inverted | Bit Indication
03h | Cathode, Inverted | Bit Indication
04h | Anode, Non-Inverted | 7-Segment Display (00h = “0”), Hundreds Column
05h | Anode, Inverted | 7-Segment Display (00h = “0”), Hundreds Column
06h | Cathode, Non-Inverted | 7-Segment Display (00h = “0”), Hundreds Column
07h | Cathode, Inverted | 7-Segment Display (00h = “0”), Hundreds Column
08h | Anode, Non-Inverted | 7-Segment Display (00h = “0”), Tens Column
09h | Anode, Inverted | 7-Segment Display (00h = “0”), Tens Column
0Ah | Cathode, Non-Inverted | 7-Segment Display (00h = “0”), Tens Column
0Bh | Cathode, Inverted | 7-Segment Display (00h = “0”), Tens Column
0Ch | Anode, Non-Inverted | 7-Segment Display (00h = “0”), Ones Column
0Dh | Anode, Inverted | 7-Segment Display (00h = “0”), Ones Column
0Eh | Cathode, Non-Inverted | 7-Segment Display (00h = “0”), Ones Column
0Fh | Cathode, Inverted | 7-Segment Display (00h = “0”), Ones Column
10h | Anode, Non-Inverted | Bar Graph
11h | Anode, Inverted | Bar Graph
12h | Cathode, Non-Inverted | Bar Graph
13h | Cathode, Inverted | Bar Graph
14h | Anode, Non-Inverted | 7-Segment Display (40h = “0”), Sign Column
15h | Anode, Inverted | 7-Segment Display (40h = “0”), Sign Column
16h | Cathode, Non-Inverted | 7-Segment Display (40h = “0”), Sign Column
17h | Cathode, Inverted | 7-Segment Display (40h = “0”), Sign Column
18h | Anode, Non-Inverted | 7-Segment Display (40h = “0”), Tens Column
19h | Anode, Inverted | 7-Segment Display (40h = “0”), Tens Column
1Ah | Cathode, Non-Inverted | 7-Segment Display (40h = “0”), Tens Column
1Bh | Cathode, Inverted | 7-Segment Display (40h = “0”), Tens Column
1Ch | Anode, Non-Inverted | 7-Segment Display (40h = “0”), Ones Column
1Dh | Anode, Inverted | 7-Segment Display (40h = “0”), Ones Column
1Eh | Cathode, Non-Inverted | 7-Segment Display (40h = “0”), Ones Column
1Fh | Cathode, Inverted | 7-Segment Display (40h = “0”), Ones Column

### 3.6.4 LED Output Examples

The figures below show four different configurations for a (2 common) x (8 data) LED matrix. Additional groups of 8 LEDs can be driven with the additional common lines, up to a total of 64 LEDs.

Figure 3.6.4-1: LED Matrix, Non-Inverted Common Anode

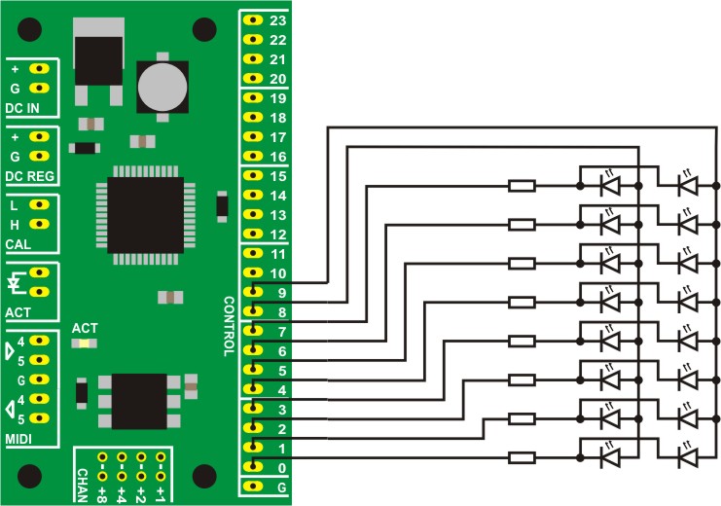
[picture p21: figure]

Figure 3.6.4-2: LED Matrix, Inverted Common Anode

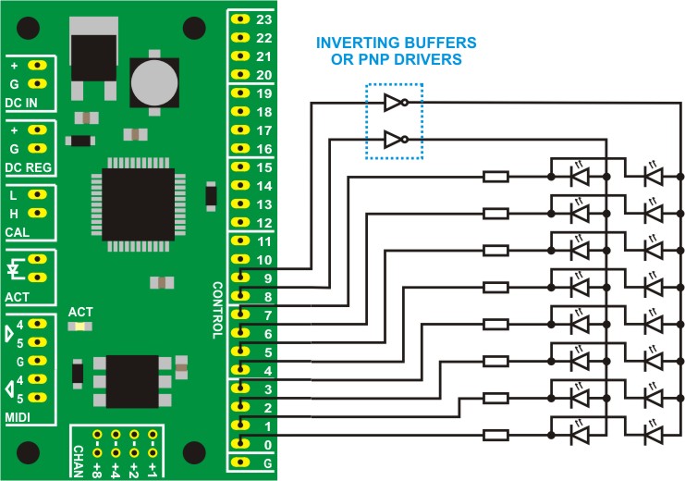
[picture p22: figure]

Figure 3.6.4-3: LED Matrix, Non-Inverted Common Cathode

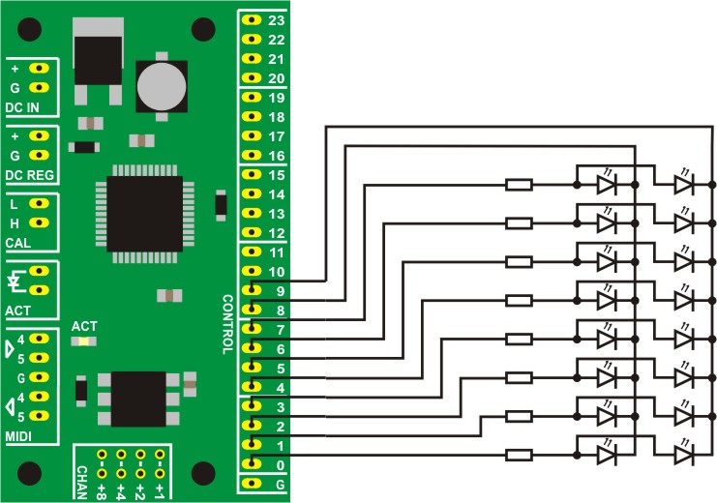
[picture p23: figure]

Figure 3.6.4-4: LED Matrix, Inverted Common Cathode

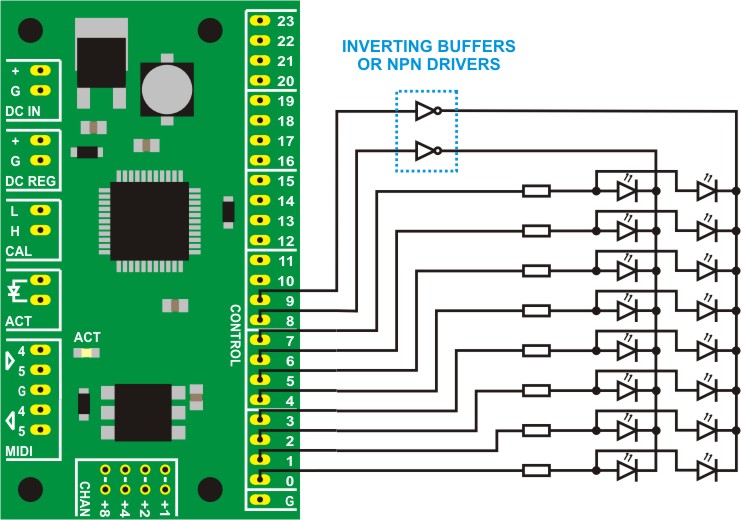
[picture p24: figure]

## 4.0 Global Configuration

The MIDI CPU has several user-configurable settings which are not associated with individual control terminals. Each setting and the associated SysEx message is described below.
The MIDI CPU acknowledges an incoming configuration message via the Activity Indicator LED.
The factory default value for each setting is described in Factory Default Configuration.

### 4.1 Matrix Note Velocity

The velocity of MIDI notes generated as a result of matrix select control terminal modes can be changed via the SysEx message described in Figure 4.1-1.
Alternatively, velocity can be changed in real time via control terminal modes Encoder Input: Matrix Note Velocity and Analog Input: Matrix Note Velocity.

Figure 4.1-1: Matrix Note Velocity SysEx Message (Hex)
Header (6 bytes) | Note Velocity (1 byte) | Footer (1 byte)
F0 00 01 5D 04 02 | vv | F7

### 4.2 Control Change (CC) “On/Off” Values

The CC value of messages generated by modes Logic Input Trigger: Control Change (CC) Toggle, Matrix Select: Control Change (CC) On/Off, and Matrix Select: Control Change (CC) Toggle can be changed via the SysEx message described in Figure 4.2-1.
Alternatively, on/off values can be changed in real time via control terminal modes: Encoder Input: Control Change (CC) “Off” Value, Encoder Input: Control Change (CC) “On” Value, Analog Input: Control Change (CC) “Off” Value, and Analog Input: Control Change (CC) “On” Value.

Figure 4.2-1: Matrix Control Change (CC) On/Off Values SysEx Message (Hex)
Header (6 bytes) | “On” Value (1 byte) | “Off” Value (1 byte) | Footer (1 byte)
F0 00 01 5D 04 03 | xx | yy | F7

### 4.3 Multipurpose Data Register Initial Values

The initial value (at power-up) contained in the multipurpose data registers can be changed via the MIDI SysEx message described in Figure 4.3-1. Values v0-v11 correspond to data register addresses 11h-1Ch (see Table 2.2.3-a).

Figure 4.3-1: Multipurpose Data Register Initial Values SysEx Message (Hex)
Header (6 bytes) | Initial Values (12 bytes) | Footer (1 byte)
F0 00 01 5D 04 04 | v0 v1 v2 v3 v4 v5 v6 v7 v8 v9 v10 v11 | F7

### 4.4 Note Transposition

The MIDI CPU can transpose locally generated notes by an amount that is adjustable in “real time”. Note transposition is configured via the SysEx message described in Figure 4.4-1.
If the register at address aa contains the value vv, note numbers are increased by the value (vv - 40h). This allows a range of transposition values between -64 (vv = 00h) and +63 (vv = 7Fh). When vv = 40h, no transposition takes place.
To disable note transposition, use the value aa = 7Fh.
The MIDI CPU transposes note numbers before performing any MIDI Number Remapping.

Figure 4.4-1: Note Transposition SysEx Message (Hex)
Header (6 bytes) | Transposition Register Address (1 byte) | Footer (1 byte)
F0 00 01 5D 04 0B | aa | F7

### 4.5 MIDI Number Remapping

The MIDI CPU can remap any locally generated note number, CC number, or program number to another before MIDI output is generated. This can be useful for unusual switch matrix configurations or for changing the musical scale of MIDI output.
Remapping for each message type is independently activated via SysEx message. See Figure 4.3-1 and Table 4.5-a.

Figure 4.5-1: MIDI Number Remapping Flags SysEx Message (Hex)
Header (6 bytes) | Remap Flags (1 byte) | Footer (1 byte)
F0 00 01 5D 04 0A | ff | F7

Table 4.5-a: MIDI Number Remapping Flags Hex Values

ff (Hex) | Program Remap | CC Remap | Note Remap
00 | off | off | off
01 | off | off | on
02 | off | on | off
03 | off | on | on
04 | on | off | off
05 | on | off | on
06 | on | on | off
07 | on | on | on

When the MIDI CPU generates a message type for which remapping is active, the (note, CC, or program) number resulting from control terminal configuration is used as a look-up address for the MIDI Number Remap Table. The value contained in the table at that address is substituted for the (note, CC, or program) number in the outgoing message.
By default, each value within the table is equal to its address: therefore, no remapping takes place. Values in the table may be updated via SysEx as described in Figure 4.5-2. The SysEx message includes the remap value for each MIDI number in order from numbers 0 to 127.
To return the MIDI Number Remap Table to its default (no remap) state, use the SysEx message described in Figure 4.5-3.

Figure 4.5-2: MIDI Number Remapping Table SysEx Message (Hex)
Header (6 bytes) | MIDI Number Remap Table Contents (128 bytes) | Footer (1 byte)
F0 00 01 5D 04 05 | n0 n1 n2 … | F7

Figure 4.5-3: MIDI Number Remapping Table Reset SysEx Message (Hex) Complete Message
(7 bytes)
F0 00 01 5D 04 06 F7

### 4.6 SysEx Data Buffer

The MIDI CPU is capable of sending arbitrary SysEx messages in response to control terminal input. See the Logic Input Trigger: System Exclusive (SysEx) control terminal mode.
The data payload of the generated SysEx message is formed from the contents of the SysEx Data Buffer. To update the contents of the buffer, send a SysEx message as shown in Figure 4.6-1. The SysEx data is written to the SysEx Data Buffer starting at address 00h. If fewer than 128 bytes are specified, the remainder of bytes in the SysEx Data Buffer is filled with the value 7Fh.

Figure 4.6-1: SysEx Data Buffer Contents SysEx Message (Hex)
Header (6 bytes) | SysEx Data Buffer Contents (up to 128 bytes) | Footer (1 byte)
F0 00 01 5D 04 07 | d0 d1 d2 … | F7

### 4.7 ADC Configuration

The MIDI CPU uses an analog-to-digital converter (ADC) to measure the voltages on control terminals configured as analog inputs. Measurements from the ADC are processed based on settings from the SysEx message shown in Figure 4.7-1.

Figure 4.7-1: ADC Configuration SysEx Message (Hex)
Header (6 bytes) | Analog Input Threshold (1 byte) | Analog Input Smoothing (1 byte) | Reference Voltage (1 byte) | Footer (1 byte)
F0 00 01 5D 04 08 | tt | ss | rr | F7

### 4.7.1 Analog Input Threshold (tt)

When a control terminal is configured as an analog input, the MIDI CPU first converts the analog signal to a 10-bit digital value, and then reduces the 10-bit value to the 7-bit resolution employed by MIDI messaging.
Due to “noise” resulting from the analog-to-digital conversion process and/or the instability of an analog input signal, analog input values may fluctuate excessively, causing the MIDI CPU to generate unwanted quantities of MIDI messages. The Analog Input Threshold is the minimum quantity by which any 10-bit analog input value must change in order to trigger message generation.
The Analog Input Threshold acts on the 10-bit input value, but is ignored whenever the resulting 7-bit input value reaches its minimum (0) or maximum (127) value.

### 4.7.2 Analog Input Smoothing (ss)

The MIDI CPU uses a rolling average algorithm to smooth the data waveform resulting from analog to digital conversion. The value of ss determines the weight of the rolling average compared to the immediate analog input value. Larger values of ss result in a smoother waveform. Smaller values of ss result in a waveform that responds more quickly to input changes. The valid range for ss is 00h to 04h.

### 4.7.3 Analog Reference Voltage (rr)

When one or more MIDI CPU control terminals are configured as analog inputs, the MIDI CPU uses two reference voltages during the analog-to-digital conversion process. These voltages, called “VREF−” and “VREF+”, represent the analog voltages that are converted to the digital values 00h and 7Fh, respectively. The MIDI CPU can use its own voltage regulator to supply the reference voltages, or it can use external reference voltages connected by the user.
External reference voltages can be useful when:
- Lower-noise analog-to-digital conversion is required
- The analog input signal does not span the entire range between MIDI CPU ground and VREG. When rr is set to 00h, the MIDI CPU will use its on-board ground as VREF−, and its on-board VREG as

VREF+.
When rr is set to 01h, the MIDI CPU will use the external VREF− and VREF+ connected by the user to control terminals 18 and 19.
See MIDI CPU Hardware User Manual for external reference voltage wiring diagrams and for additional details regarding VREG.
Regardless of the reference voltages used, analog input voltages must not exceed the limits described in MIDI CPU Hardware User Manual.

### 4.8 Active Sense On/Off

During periods of inactivity, a MIDI device can send Active Sense messages to notify the receiving device that the MIDI link is still operating. Active Sense messages are automatically generated at the rate of approximately 4 per second when no other MIDI data is being generated. This function is not required for most applications.
MIDI CPU Active Sense generation can be enabled or disabled using the SysEx message shown in Figure 4.8-1. When aa = 00h, Active Sense is disabled. When aa = 01h, Active Sense is enabled.

Figure 4.8-1: Active Sense On/Off SysEx Message (Hex)
Header (6 bytes) | Active Sense (1 byte) | Footer (1 byte)
F0 00 01 5D 04 09 | aa | F7

## 5.0 Configuration Retrieval

At any time, the current MIDI CPU configuration can be retrieved via SysEx Configuration Retrieval Messages. When the MIDI CPU receives a SysEx Configuration Retrieval Message at its MIDI IN port, it will output the associated configuration data in the form of a SysEx Configuration Message.
The format of each SysEx Configuration Retrieval message is shown in Table 5-a.

Table 5-a: SysEx Configuration Retrieval Messages
SysEx Configuration Retrieval Message (Hex) | Resulting Output
F0 00 01 5D 04 00 01 00 F7 | Control terminal configurations, all terminals, layer 00h. Formatted as Control Terminal Configuration SysEx Message.
F0 00 01 5D 04 00 01 01 F7 | Control terminal configurations, all terminals, layer 01h. Formatted as Control Terminal Configuration SysEx Message.
F0 00 01 5D 04 00 01 02 F7 | Control terminal configurations, all terminals, layer 02h. Formatted as Control Terminal Configuration SysEx Message.
F0 00 01 5D 04 00 01 03 F7 | Control terminal configurations, all terminals, layer 03h. Formatted as Control Terminal Configuration SysEx Message.
F0 00 01 5D 04 00 02 00 F7 | Matrix Note Velocity SysEx Message
F0 00 01 5D 04 00 03 00 F7 | Control Change (CC) “On/Off” Values SysEx Message
F0 00 01 5D 04 00 04 00 F7 | Multipurpose Data Register Initial Values SysEx Message
F0 00 01 5D 04 00 05 00 F7 | MIDI Number Remapping Table SysEx Message
F0 00 01 5D 04 00 07 00 F7 | SysEx Data Buffer Contents SysEx Message
F0 00 01 5D 04 00 08 00 F7 | ADC Configuration SysEx Message
F0 00 01 5D 04 00 09 00 F7 | Active Sense On/Off SysEx Message
F0 00 01 5D 04 00 0A 00 F7 | MIDI Number Remapping Flags SysEx Message
F0 00 01 5D 04 00 0B 00 F7 | Note Transposition SysEx Message
F0 00 01 5D 04 00 7D 00 F7 | Firmware Version SysEx Message
F0 00 01 5D 04 00 7F 00 F7 | Configuration dump: all of the configuration data listed above, formatted as a series of SysEx messages.

## 6.0 MIDI Channel Selection Jumper

Depending on Control Terminal Configuration, the MIDI Channel Selection Jumper can be used to select the MIDI channel for messages sent or received by the MIDI CPU. See MIDI CPU Hardware User Manual for diagrams.
When none of the channel jumpers are shorted, the channel setting is 1. Shorting the “+1” jumper adds 1 to the channel setting, the “+2” adds 2 to the channel setting, etc.
For example, if both the “+2” and “+4” jumpers are shorted, the resulting channel setting is 1 + 2 + 4 = 7.

## 7.0 Activity Indicator LED

The MIDI CPU Activity Indicator LED performs several functions:
- Self Test: Upon power-up or device reset, the Activity LED lights briefly before normal operation begins.
- Configuration Update Indication: When the MIDI CPU configuration is updated via a MIDI SysEx message, the device will reset, followed by the LED self-test. If no LED activity is observed, then the attempted configuration was unsuccessful.
- MIDI Activity Indication: The LED blinks when locally generated or merged MIDI events are sent via the MIDI CPU MIDI Out port.
- Firmware Update Mode Indication: The LED will remain lighted while the MIDI CPU awaits a firmware update SysEx message.
- Firmware Update Error: The LED blinks continuously when the receipt of a firmware update SysEx message has failed, or when the firmware has become corrupt.

## 8.0 Firmware Update

MIDI CPU firmware can be upgraded via MIDI SysEx message. Firmware update files, when available, can be downloaded from: http://highlyliquid.com/midi-cpu

### 8.1 Firmware Update Procedure

1. Download and unzip the firmware update SysEx message. The resulting file should have the extension “.syx”.
2. Disconnect power to the MIDI CPU.
3. Connect the “CAL L” terminal to ground.
4. Re-connect power to the MIDI CPU. The Activity LED will remain lighted.
5. Send the firmware update SysEx message to the MIDI CPU. Transmission of the message may require several seconds.
6. Upon completion of the update, the Activity LED will deactivate.
7. Disconnect the “CAL L” terminal.
8. Disconnect power to the MIDI CPU.
9. Power up the MIDI CPU, and send the following SysEx message: F0 00 01 5D 04 0B 7F F7

### 8.2 Notes

- When updating firmware, use a MIDI CPU power supply voltage of 6.0V or greater.
- Do not interrupt the transmission of the firmware update SysEx message.
- A continuously blinking Activity LED indicates an error in the transmission of the firmware update SysEx message.
- If a continuously blinking Activity LED is observed, repeat the procedure from the beginning.

### 8.3 Firmware Version SysEx Message

During normal operation, the current MIDI CPU firmware version can be retrieved by sending the SysEx message shown in Figure 8.3-1. In response, the MIDI CPU will send a SysEx message as shown in Figure 8.3-2. The key to firmware versions is shown in Table 8.3-a.

Figure 8.3-1: Firmware Version Retrieval SysEx Message (Hex)
Complete Message (9 bytes) F0 00 01 5D 04 00 7D 00 F7

Figure 8.3-2: Firmware Version SysEx Message (Hex)
Header (6 bytes) | Version (1 byte) | Footer (1 byte)
F0 00 01 5D 04 7D | vv | F7

Table 8.3-a: Firmware Versions
vv (Hex) | Firmware Version
00 | 1.0
01 | 1.1
02 1.2
03 | 1.3 (beta releases)
04 1.2a (includes a fix for a | bug in v1.2)
05 | 1.3 (production version)
06 | 1.4 (beta releases)
07 | 1.4 (production version)
08 thru 7F | Reserved for future versions.

## 9.0 Factory Default Configuration

The MIDI CPU “factory default” configuration can be described in terms of equivalent configuration SysEx messages.

Figure 9-1: Factory Default Control Terminal Configuration: Layer 00h (Part 1 of 3)
SysEx Data (Hex) | Meaning
F0 00 01 5D 04 01 | Fixed Header
00 | Configuration Layer 0
00 00 44 00 3C 7F | Control Terminal 0: Transition High to Low Logic Input Trigger: Note On: Note 60, Velocity 127
00 01 44 00 3C 00 | Control Terminal 0: Transition Low to High Logic Input Trigger: Note On: Note 60, Velocity 0 (Velocity 0 = Note Off)
01 00 44 00 3D 7F | Control Terminal 1: Transition High to Low Logic Input Trigger: Note On: Note 61, Velocity 127
01 01 44 00 3D 00 | Control Terminal 1: Transition Low to High Logic Input Trigger: Note On: Note 61, Velocity 0 (Velocity 0 = Note Off)
02 00 44 00 3E 7F | Control Terminal 2: Transition High to Low Logic Input Trigger: Note On: Note 62, Velocity 127
02 01 44 00 3E 00 | Control Terminal 2: Transition Low to High Logic Input Trigger: Note On: Note 62, Velocity 0 (Velocity 0 = Note Off)
03 00 44 00 3F 7F | Control Terminal 3: Transition High to Low Logic Input Trigger: Note On: Note 63, Velocity 127
03 01 44 00 3F 00 | Control Terminal 3: Transition Low to High Logic Input Trigger: Note On: Note 63, Velocity 0 (Velocity 0 = Note Off)
04 00 44 00 40 7F | Control Terminal 4: Transition High to Low Logic Input Trigger: Note On: Note 64, Velocity 127
04 01 44 00 40 00 | Control Terminal 4: Transition Low to High Logic Input Trigger: Note On: Note 64, Velocity 0 (Velocity 0 = Note Off)
05 00 44 00 41 7F | Control Terminal 5: Transition High to Low Logic Input Trigger: Note On: Note 65, Velocity 127
05 01 44 00 41 00 | Control Terminal 5: Transition Low to High Logic Input Trigger: Note On: Note 65, Velocity 0 (Velocity 0 = Note Off)
06 00 44 00 42 7F | Control Terminal 6: Transition High to Low Logic Input Trigger: Note On: Note 66, Velocity 127
06 01 44 00 42 00 | Control Terminal 6: Transition Low to High Logic Input Trigger: Note On: Note 66, Velocity 0 (Velocity 0 = Note Off)
07 00 44 00 43 7F | Control Terminal 7: Transition High to Low Logic Input Trigger: Note On: Note 67, Velocity 127
07 01 44 00 43 00 | Control Terminal 7: Transition Low to High Logic Input Trigger: Note On: Note 67, Velocity 0 (Velocity 0 = Note Off)

Figure 9-2: Factory Default Control Terminal Configuration: Layer 00h (Part 2 of 3)
SysEx Data (Hex) | Meaning
08 00 44 00 44 7F | Control Terminal 8: Transition High to Low Logic Input Trigger: Note On: Note 68, Velocity 127
08 01 44 00 44 00 | Control Terminal 8: Transition Low to High Logic Input Trigger: Note On: Note 68, Velocity 0 (Velocity 0 = Note Off)
09 00 44 00 45 7F | Control Terminal 9: Transition High to Low Logic Input Trigger: Note On: Note 69, Velocity 127
09 01 44 00 45 00 | Control Terminal 9: Transition Low to High Logic Input Trigger: Note On: Note 69, Velocity 0 (Velocity 0 = Note Off)
0A 00 44 00 46 7F | Control Terminal 10: Transition High to Low Logic Input Trigger: Note On: Note 70, Velocity 127
0A 01 44 00 46 00 | Control Terminal 10: Transition Low to High Logic Input Trigger: Note On: Note 70, Velocity 0 (Velocity 0 = Note Off)
0B 00 44 00 47 7F | Control Terminal 11: Transition High to Low Logic Input Trigger: Note On: Note 71, Velocity 127
0B 01 44 00 47 00 | Control Terminal 11: Transition Low to High Logic Input Trigger: Note On: Note 71, Velocity 0 (Velocity 0 = Note Off)
0C 00 44 00 48 7F | Control Terminal 12: Transition High to Low Logic Input Trigger: Note On: Note 72, Velocity 127
0C 01 44 00 48 00 | Control Terminal 12: Transition Low to High Logic Input Trigger: Note On: Note 72, Velocity 0 (Velocity 0 = Note Off)
0D 00 44 00 49 7F | Control Terminal 13: Transition High to Low Logic Input Trigger: Note On: Note 73, Velocity 127
0D 01 44 00 49 00 | Control Terminal 13: Transition Low to High Logic Input Trigger: Note On: Note 73, Velocity 0 (Velocity 0 = Note Off)
0E 00 44 00 4A 7F | Control Terminal 14: Transition High to Low Logic Input Trigger: Note On: Note 74, Velocity 127
0E 01 44 00 4A 00 | Control Terminal 14: Transition Low to High Logic Input Trigger: Note On: Note 74, Velocity 0 (Velocity 0 = Note Off)
0F 00 44 00 4B 7F | Control Terminal 15: Transition High to Low Logic Input Trigger: Note On: Note 75, Velocity 127
0F 01 44 00 4B 00 | Control Terminal 15: Transition Low to High Logic Input Trigger: Note On: Note 75, Velocity 0 (Velocity 0 = Note Off)

Figure 9-3: Factory Default Control Terminal Configuration: Layer 00h (Part 3 of 3)
SysEx Data (Hex) | Meaning
10 00 44 00 4C 7F | Control Terminal 16: Transition High to Low Logic Input Trigger: Note On: Note 76, Velocity 127
10 01 44 00 4C 00 | Control Terminal 16: Transition Low to High Logic Input Trigger: Note On: Note 76, Velocity 0 (Velocity 0 = Note Off)
11 00 44 00 4D 7F | Control Terminal 17: Transition High to Low Logic Input Trigger: Note On: Note 77, Velocity 127
11 01 44 00 4D 00 | Control Terminal 17: Transition Low to High Logic Input Trigger: Note On: Note 77, Velocity 0 (Velocity 0 = Note Off)
12 00 44 00 4E 7F | Control Terminal 18: Transition High to Low Logic Input Trigger: Note On: Note 78, Velocity 127
12 01 44 00 4E 00 | Control Terminal 18: Transition Low to High Logic Input Trigger: Note On: Note 78, Velocity 0 (Velocity 0 = Note Off)
13 00 44 00 4F 7F | Control Terminal 19: Transition High to Low Logic Input Trigger: Note On: Note 79, Velocity 127
13 01 44 00 4F 00 | Control Terminal 19: Transition Low to High Logic Input Trigger: Note On: Note 79, Velocity 0 (Velocity 0 = Note Off)
14 00 44 00 50 7F | Control Terminal 20: Transition High to Low Logic Input Trigger: Note On: Note 80, Velocity 127
14 01 44 00 50 00 | Control Terminal 20: Transition Low to High Logic Input Trigger: Note On: Note 80, Velocity 0 (Velocity 0 = Note Off)
15 00 44 00 51 7F | Control Terminal 21: Transition High to Low Logic Input Trigger: Note On: Note 81, Velocity 127
15 01 44 00 51 00 | Control Terminal 21: Transition Low to High Logic Input Trigger: Note On: Note 81, Velocity 0 (Velocity 0 = Note Off)
16 00 44 00 52 7F | Control Terminal 22: Transition High to Low Logic Input Trigger: Note On: Note 82, Velocity 127
16 01 44 00 52 00 | Control Terminal 22: Transition Low to High Logic Input Trigger: Note On: Note 82, Velocity 0 (Velocity 0 = Note Off)
17 00 44 00 53 7F | Control Terminal 23: Transition High to Low Logic Input Trigger: Note On: Note 83, Velocity 127
17 01 44 00 53 00 | Control Terminal 23: Transition Low to High Logic Input Trigger: Note On: Note 83, Velocity 0 (Velocity 0 = Note Off)
F7 | Fixed Footer

Figure 9-4: Factory Default Control Terminal Configuration: Layers 01h, 02h, 03h
SysEx Data (Hex) | Meaning
F0 00 01 5D 04 01 | Fixed Header
[01, 02, 03] | Configuration Layers 01h, 02h, 03h
[00..17] 00 7F 00 00 00 | For each control terminal 0 thru 23: Transition High to Low Logic Input Data Only
[00..17] 01 7F 00 00 00 | For each control terminal 0 thru 23: Transition Low to High Logic Input Data Only
F7 | Fixed Footer

Figure 9-5: Factory Default Matrix Note Velocity
SysEx Data (Hex) | Meaning
F0 00 01 5D 04 02 7F F7 | For any MIDI notes generated via a switch matrix, the default note velocity is 127.

Figure 9-6: Factory Default Control Change (CC) “On/Off” Values
SysEx Data (Hex) | Meaning
F0 00 01 5D 04 03 7F 00 F7 | For any CC messages generated via a switch matrix or CC “toggle” mode, the default “on” CC value is 127 and the default “off” CC value is 0.

Figure 9-7: Factory Default Multipurpose Data Register Initial Values
SysEx Data (Hex) | Meaning
F0 00 01 5D 04 04 00 00 00 00 00 00 00 00 00 00 00 00 F7 | At power up, each Multipurpose Data Register is initialized with the value 0.

Figure 9-8: Factory Default Note Transposition
SysEx Data (Hex) | Meaning
F0 00 01 5D 04 0B 7F F7 | Note transposition is deactivated.

Figure 9-9: Factory Default MIDI Number Remapping Flags
SysEx Data (Hex) | Meaning
F0 00 01 5D 04 0A 00 F7 | Remapping is deactivated for all message types.

Figure 9-10: Factory Default MIDI Number Mapping
SysEx Data (Hex) | Meaning
F0 00 01 5D 04 05 00 01 02 03 04 05 06 07 08 09 0A 0B 0C 0D 0E 0F 10 11 12 13 14 15 16 17 18 19 1A 1B 1C 1D 1E 1F 20 21 22 23 24 25 26 27 28 29 2A 2B 2C 2D 2E 2F 30 31 32 33 34 35 36 37 38 39 3A 3B 3C 3D 3E 3F 40 41 42 43 44 45 46 47 48 49 4A 4B 4C 4D 4E 4F 50 51 52 53 54 55 56 57 58 59 5A 5B 5C 5D 5E 5F 60 61 62 63 64 65 66 67 68 69 6A 6B 6C 6D 6E 6F 70 71 72 73 74 75 76 77 78 79 7A 7B 7C 7D 6E 7F F7 | Each number is mapped to itself. Effectively, no remapping takes place.

Figure 9-11: Factory Default SysEx Data Buffer Contents
SysEx Data (Hex) | Meaning
F0 00 01 5D 04 07 00 01 02 03 04 05 06 07 08 09 0A 0B 0C 0D 0E 0F 10 11 12 13 14 15 16 17 18 19 1A 1B 1C 1D 1E 1F 20 21 22 23 24 25 26 27 28 29 2A 2B 2C 2D 2E 2F 30 31 32 33 34 35 36 37 38 39 3A 3B 3C 3D 3E 3F 40 41 42 43 44 45 46 47 48 49 4A 4B 4C 4D 4E 4F 50 51 52 53 54 55 56 57 58 59 5A 5B 5C 5D 5E 5F 60 61 62 63 64 65 66 67 68 69 6A 6B 6C 6D 6E 6F 70 71 72 73 74 75 76 77 78 79 7A 7B 7C 7D 6E 7F F7 | The SysEx data buffer contains arbitrary data.

Figure 9-12: Factory Default ADC Configuration
SysEx Data (Hex) | Meaning
F0 00 01 5D 04 08 06 04 00 F7 | Analog Input Threshold = 6; Analog Input Smoothing = 4; Reference Voltage = On-Board.

Figure 9-13: Factory Default Active Sense
SysEx Data (Hex) | Meaning
F0 00 01 5D 04 09 00 F7 | Generation of Active Sense messages is disabled.

## 10.0 Configuration Examples

Configuration examples are provided below. Wiring methods and control terminal configurations can be mixed and matched between the different examples as desired. See MIDI CPU Hardware User Manual for the I/O capabilities of each control terminal.

### 10.1 CC Output: Potentiometers, Encoders, Switches

In this example the following input devices are connected to the MIDI CPU (See Figure 10.1-1):
- Control terminals 0 thru 7: SPST toggle switches (8 total)
- Control terminals 8 thru 15: Rotary encoders (4 total)
- Control terminals 16 thru 23: Potentiometers (8 total)
Input devices are used to generate Control Change (CC) messages, each with a unique CC number. Potentiometers generate CC values based on wiper position, encoders generate incremented/decremented CC values upon adjustment, and toggle switches generate fixed CC “off” and “on” values when opened/closed. The MIDI channel for all messages is specified by the MIDI Channel Selection Jumper. See Figure 10.1-2 and Figure 10.1-3 for the contents of the Control Terminal Configuration SysEx Message.

Figure 10.1-1: Wiring Diagram


Figure 10.1-2: Control Terminal Configuration (Part 1 of 2)
SysEx Data (Hex) | Meaning
F0 00 01 5D 04 01 | Fixed Header
00 | Configuration Layer 0
00 00 4C 00 00 7F | Control Terminal 0: Transition High to Low Logic Input Trigger: CC: CC Number 0, CC Value 127
00 01 4C 00 00 00 | Control Terminal 0: Transition Low to High Logic Input Trigger: CC: CC Number 0, CC Value 0
01 00 4C 00 01 7F | Control Terminal 1: Transition High to Low Logic Input Trigger: CC: CC Number 1, CC Value 127
01 01 4C 00 01 00 | Control Terminal 1: Transition Low to High Logic Input Trigger: CC: CC Number 1, CC Value 0
02 00 4C 00 02 7F | Control Terminal 2: Transition High to Low Logic Input Trigger: CC: CC Number 2, CC Value 127
02 01 4C 00 02 00 | Control Terminal 2: Transition Low to High Logic Input Trigger: CC: CC Number 2, CC Value 0
03 00 4C 00 03 7F | Control Terminal 3: Transition High to Low Logic Input Trigger: CC: CC Number 3, CC Value 127
03 01 4C 00 03 00 | Control Terminal 3: Transition Low to High Logic Input Trigger: CC: CC Number 3, CC Value 0
04 00 4C 00 04 7F | Control Terminal 4: Transition High to Low Logic Input Trigger: CC: CC Number 4, CC Value 127
04 01 4C 00 04 00 | Control Terminal 4: Transition Low to High Logic Input Trigger: CC: CC Number 4, CC Value 0
05 00 4C 00 05 7F | Control Terminal 5: Transition High to Low Logic Input Trigger: CC: CC Number 5, CC Value 127
05 01 4C 00 05 00 | Control Terminal 5: Transition Low to High Logic Input Trigger: CC: CC Number 5, CC Value 0
06 00 4C 00 06 7F | Control Terminal 6: Transition High to Low Logic Input Trigger: CC: CC Number 6, CC Value 127
06 01 4C 00 06 00 | Control Terminal 6: Transition Low to High Logic Input Trigger: CC: CC Number 6, CC Value 0
07 00 4C 00 07 7F | Control Terminal 7: Transition High to Low Logic Input Trigger: CC: CC Number 7, CC Value 127
07 01 4C 00 07 00 | Control Terminal 7: Transition Low to High Logic Input Trigger: CC: CC Number 7, CC Value 0

Figure 10.1-3: Control Terminal Configuration (Part 2 of 2)
SysEx Data (Hex) | Meaning
08 00 14 00 08 15 | Control Terminal 8 Encoder Input: CC: CC Number 8, CC Value from encoder
09 00 14 00 08 15 | Control Terminal 9 Encoder Input: CC: CC Number 8, CC Value from encoder
0A 00 14 00 09 16 | Control Terminal 10 Encoder Input: CC: CC Number 9, CC Value from encoder
0B 00 14 00 09 16 | Control Terminal 11 Encoder Input: CC: CC Number 9, CC Value from encoder
0C 00 14 00 0A 17 | Control Terminal 12 Encoder Input: CC: CC Number 10, CC Value from encoder
0D 00 14 00 0A 17 | Control Terminal 13 Encoder Input: CC: CC Number 10, CC Value from encoder
0E 00 14 00 0B 18 | Control Terminal 14 Encoder Input: CC: CC Number 11, CC Value from encoder
0F 00 14 00 0B 18 | Control Terminal 15 Encoder Input: CC: CC Number 11, CC Value from encoder
10 00 04 00 0C 03 | Control Terminal 16 Analog Input: CC: CC Number 12, CC Value from potentiometer
11 00 04 00 0D 04 | Control Terminal 17 Analog Input: CC: CC Number 13, CC Value from potentiometer
12 00 04 00 0E 05 | Control Terminal 18 Analog Input: CC: CC Number 14, CC Value from potentiometer
13 00 04 00 0F 06 | Control Terminal 19 Analog Input: CC: CC Number 15, CC Value from potentiometer
14 00 04 00 10 07 | Control Terminal 20 Analog Input: CC: CC Number 16, CC Value from potentiometer
15 00 04 00 11 08 | Control Terminal 21 Analog Input: CC: CC Number 17, CC Value from potentiometer
16 00 04 00 12 09 | Control Terminal 22 Analog Input: CC: CC Number 18, CC Value from potentiometer
17 00 04 00 13 0A | Control Terminal 23 Analog Input: CC: CC Number 19, CC Value from potentiometer
F7 | Fixed Footer

### 10.2 49-Key Keyboard Controller with Matrixed Switch Input, Velocity Knob, Program Selector

In this example, a 49-keyswitch matrix triggers MIDI notes, a potentiometer adjusts the note velocity, and a rotary encoder is used for patch selection (Program Change).
Control terminals 0 thru 7 are the matrix data inputs, while control terminals 8 thru 14 are the matrix select outputs.

Figure 10.2-1: Wiring Diagram


Figure 10.2-2: Control Terminal Configuration (Part 1 of 2)
SysEx Data (Hex) | Meaning
F0 00 01 5D 04 01 | Fixed Header
00 | Configuration Layer 0
00 00 7F 00 00 00 | Control Terminal 0: Transition High to Low Logic Input Data Only
00 01 7F 00 00 00 | Control Terminal 0: Transition Low to High Logic Input Data Only
01 00 7F 00 00 00 | Control Terminal 1: Transition High to Low Logic Input Data Only
01 01 7F 00 00 00 | Control Terminal 1: Transition Low to High Logic Input Data Only
02 00 7F 00 00 00 | Control Terminal 2: Transition High to Low Logic Input Data Only
02 01 7F 00 00 00 | Control Terminal 2: Transition Low to High Logic Input Data Only
03 00 7F 00 00 00 | Control Terminal 3: Transition High to Low Logic Input Data Only
03 01 7F 00 00 00 | Control Terminal 3: Transition Low to High Logic Input Data Only
04 00 7F 00 00 00 | Control Terminal 4: Transition High to Low Logic Input Data Only
04 01 7F 00 00 00 | Control Terminal 4: Transition Low to High Logic Input Data Only
05 00 7F 00 00 00 | Control Terminal 5: Transition High to Low Logic Input Data Only
05 01 7F 00 00 00 | Control Terminal 5: Transition Low to High Logic Input Data Only
06 00 7F 00 00 00 | Control Terminal 6: Transition High to Low Logic Input Data Only
06 01 7F 00 00 00 | Control Terminal 6: Transition Low to High Logic Input Data Only
07 00 7F 00 00 00 | Control Terminal 7: Transition High to Low Logic Input Data Only
07 01 7F 00 00 00 | Control Terminal 7: Transition Low to High Logic Input Data Only

Figure 10.2-3: Control Terminal Configuration (Part 2 of 2)
SysEx Data (Hex) | Meaning
08 00 2C 00 24 0E | Control Terminal 8 Matrix Select Output: Data Register 00h, note number 36
09 00 2C 00 25 00 | Control Terminal 9 Matrix Select Output: Data Register 00h, note numbers 37-44
0A 00 2C 00 2D 00 | Control Terminal 10 Matrix Select Output: Data Register 00h, note numbers 45-52
0B 00 2C 00 35 00 | Control Terminal 11 Matrix Select Output: Data Register 00h, note numbers 53-60
0C 00 2C 00 3D 00 | Control Terminal 12 Matrix Select Output: Data Register 00h, note numbers 61-68
0D 00 2C 00 45 00 | Control Terminal 13 Matrix Select Output: Data Register 00h, note numbers 69-76
0E 00 2C 00 4D 00 | Control Terminal 14 Matrix Select Output: Data Register 00h, note numbers 77-84
12 00 16 00 1A 00 | Control Terminal 18 Encoder Input: Program Change
13 00 16 00 1A 00 | Control Terminal 19 Encoder Input: Program Change
17 00 0A 00 00 00 | Control Terminal 23 Analog Input: Matrix Note Velocity
F7 | Fixed Footer

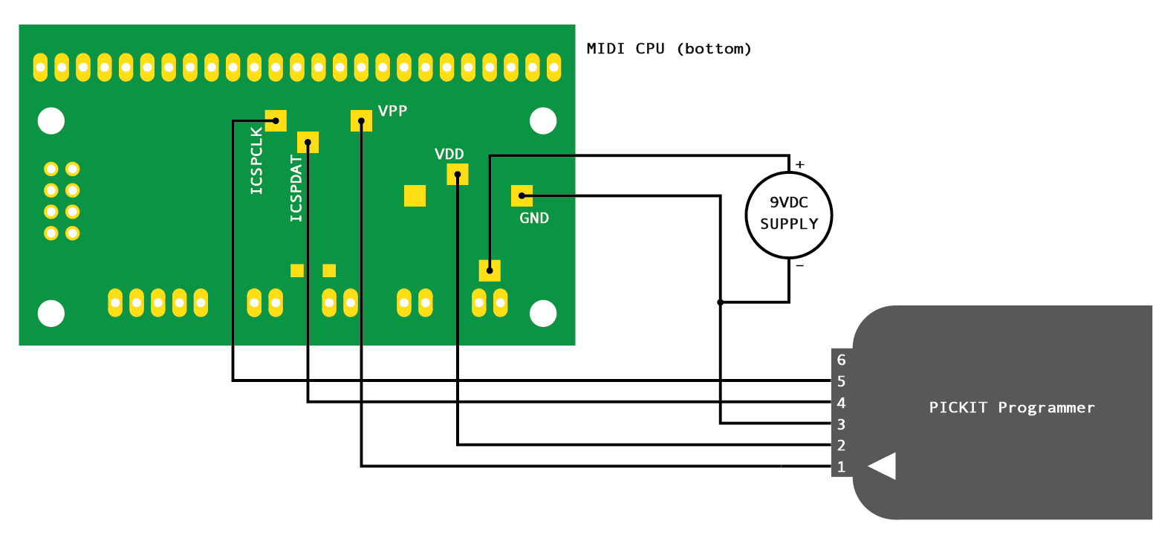
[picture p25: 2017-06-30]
doc/MIDI-CPU-ICSP.png

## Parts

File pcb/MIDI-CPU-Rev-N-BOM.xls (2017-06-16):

 | Bill of Materials
 | MIDI CPU Rev N
Item # | SMT Qty | Thru Qty | PCB Side | Ref Des | MFG Part No. | Description | Package
1 | 5 |  | Top | C1..C5 | C0805C104K3RACTU | Cap, 0.1uF, 25V, X7R | 0805
2 | 1 |  | Top | C6 | UWT1C101MCL1GB | Cap, 100uF, 16V | 6.3mm
3 | 2 |  | Top | D1, D2 | MBRX140-TP | Diode, Schottky | SOD123
4 | 1 |  | Top | D3 | 1N4148W-TP | Diode, Small Signal | SOD123
5 | 1 |  | Top | LED1 | SML-LXT0805IW-TR | LED | 0805
6 | 3 |  | Bottom | RN1..RN3 | 745C101103JP | Resistor Net, 10K | 2512
7 | 1 |  | Bottom | RN4 | 744C083221JP | Resistor Net, 220R | 2012
8 | 1 |  | Bottom | RN5 | 744C083102JP | Resistor Net, 1K | 2012
9 | 1 |  | Top | U1 | PIC16F887-I/PT | Microcontroller | TQFP-44
10 | 1 |  | Top | U2 | LM2931ADT50R | Voltage Regulator | DPAK
11 | 1 |  | Top | U3 | PC900V0NIPXF | Optoisolator | PDIP-6 Gull Wing
Totals: | 18 | 0

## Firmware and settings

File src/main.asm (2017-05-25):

; MIDI CPU
; copyright John Staskevich, 2017
; john@codeandcopper.com
;
; This work is licensed under a Creative Commons Attribution 4.0 International License.
; http://creativecommons.org/licenses/by/4.0/
;
; main.asm
;
; Boot sequence and main program loop.
;
		list		p=16f887
   		#include	<p16f887.inc>

;Configuration Bits

; no code/data protect, no BOR
;		__CONFIG _CONFIG1, 0x20E4
; no code/data protect, with BOR
;		__CONFIG _CONFIG1, 0x23E4
; with code/data protect, no BOR
;		__CONFIG _CONFIG1, 0x2024
; with code/data protect, with BOR
		__CONFIG _CONFIG1, 0x2324



; other stuff
		__CONFIG _CONFIG2, 0x02FF

   		#include	<mc.inc>

; ==================================================================
;
; External Functions
;
; ==================================================================

		EXTERN	inbound_sysex_finish
		EXTERN	main_init
		EXTERN	read_pin_config
		EXTERN	combine_channel_with_status
		EXTERN	load_d0_from_address
		EXTERN	load_d1_from_address
		EXTERN	send_midi_byte
		EXTERN	send_midi_local
		EXTERN	read_logic_inputs
		EXTERN	read_matrices
		EXTERN	read_analog_inputs
		EXTERN	process_inbound_midi
		EXTERN	update_leds

; ==================================================================
;
; Global Functions
;
; ==================================================================

		GLOBAL	poll

; ==================================================================
; ==================================================================
; ==================================================================
;
; PROGRAM
;
; ==================================================================
; ==================================================================
; ==================================================================

reset	code	0x00
		goto	start


main	code	0x700
start
; ===================================
;
; Configure the clock
;
; ===================================

; Configure the internal clock
		banksel	OSCCON
		movlw	B'01110000'
		movwf	OSCCON
; Enable PORTB pull-ups (so there are no floating inputs)
		bcf		OPTION_REG,7

; configure ACT terminal for digital output
; turn on the ACT LED
		bcf		TRISA,6
		banksel	PORTA
;		bcf		PORTA,6
		clrf	PORTA

; check for firmware update state
		btfsc	PORTC,5
		goto	start_go_normal
;		btfsc	PORTC,4
;		goto	start_go_normal

; /////////////FIRMWARE UPDATE MODE

; init STATE_FLAGS
		movlw	B'00001000'
		movwf	STATE_FLAGS

; ===================================
;
; Configure the USART
;
; ===================================
; Set up the USART
		banksel	PIE1
; Enable receive interrupt
		bsf		PIE1,5
; Set up the baud rate generator
; 31.25kHz = 8MHz / (16 (15 + 1))
		movlw	0x0f
		movwf	SPBRG
; Set the transmit control bits
		movlw	B'00100110'
		movwf	TXSTA
		banksel PORTA
; Set the receive control bits
		movlw	B'10010000'
		movwf	RCSTA
		banksel	PORTA
; ===================================
;
; Enable global interrupts
;
; ===================================

; Enable global & peripheral interrupts
		movlw	B'11000000'
		movwf	INTCON

; do nothing while isr handles firmware update
start_wait_for_update
		goto	start_wait_for_update

start_go_normal
; checksum the firmware
		clrf	TEMP
		clrf	TEMP2
		banksel	EEADR
		clrf	EEADR
		clrf	EEADRH

; add all opcodes from 0x0000 to 0x1BFF
checksum_loop
		banksel	EECON1
		bsf		EECON1,EEPGD
		bsf		EECON1,RD
		nop
		nop
; sum into TEMP2,TEMP
		banksel	EEDAT
		movfw	EEDAT
		addwf	TEMP,f
		btfsc	STATUS,C
		incf	TEMP2,f
		movfw	EEDATH
		addwf	TEMP2,f
; increment program address
		incfsz	EEADR,f
		goto	checksum_loop
		incf	EEADRH,f
		movlw	0x1C
		subwf	EEADRH,w
		bnz		checksum_loop
; sum value is now in TEMP2,TEMP
; store for debugging
; high byte
;		movfw	TEMP2
;		movwf	EEDAT
;		movlw	PROM_CHECKSUM_TEST
;		movwf	EEADR
;		banksel	EECON1
;		bcf		EECON1,EEPGD
;		bsf		EECON1,WREN
;		movlw	0x55
;		movwf	EECON2
;		movlw	0xAA
;		movwf	EECON2
;		bsf		EECON1,WR
; wait for write complete
;		banksel	PIR2
;		btfss	PIR2,EEIF
;		goto	$-1
;		bcf		PIR2,EEIF
; low byte
;		banksel	EEADR
;		movfw	TEMP
;		movwf	EEDAT
;		incf	EEADR,f
;		banksel	EECON1
;		bsf		EECON1,WREN
;		movlw	0x55
;		movwf	EECON2
;		movlw	0xAA
;		movwf	EECON2
;		bsf		EECON1,WR
; wait for write complete
;		banksel	PIR2
;		btfss	PIR2,EEIF
;		goto	$-1
;		bcf		PIR2,EEIF

; add in checksum from EEPROM and check for 0
		banksel	EEADR
		movlw	PROM_CHECKSUM
		movwf	EEADR
		banksel	EECON1
		bcf		EECON1,EEPGD
		bsf		EECON1,RD
		banksel	EEDAT
		movfw	EEDAT
		movwf	TEMP4
		incf	EEADR,f
		banksel	EECON1
		bsf		EECON1,RD
		banksel	EEDAT
		movfw	EEDAT
		movwf	TEMP3
; complement value is now in TEMP4,TEMP3
		movlw	0x01
		addwf	TEMP3,f
		btfsc	STATUS,C
		incf	TEMP4,f
		movfw	TEMP3
		addwf	TEMP,f
		btfsc	STATUS,C
		incf	TEMP4,f
		movfw	TEMP4
		addwf	TEMP2,f
; check for zero
		movfw	TEMP2
		bnz		checksum_error
		movfw	TEMP
		bnz		checksum_error

checksum_ok
; continue with init
		banksel	PORTA
		pagesel	start_normal
		goto	start_normal

checksum_error
; blink the activity LED and do nothing.
		banksel	PORTA
checksum_error_blink
; PORTA read-mod-write ok here
		bsf		PORTA,6
		clrf	COUNTER_L
		clrf	COUNTER_H
		decfsz	COUNTER_L,f
		goto	$-1
		decfsz	COUNTER_H,f
		goto	$-3

; PORTA read-mod-write ok here
		bcf		PORTA,6
		clrf	COUNTER_L
		clrf	COUNTER_H
		decfsz	COUNTER_L,f
		goto	$-1
		decfsz	COUNTER_H,f
		goto	$-3
		goto	checksum_error_blink


main_normal	code	0x0E00
;main_normal	code
start_normal
; ==================================================================
;
; Device Initialization
;
; ==================================================================

		pagesel	main_init
		call	main_init
		pagesel	poll



; ==================================================================
;
; poll inputs while processing incoming MIDI data
;
; ==================================================================

poll
; always check to see if a MIDI CPU-specific SysEx message is being
; processed.  If so, don't bother to process any inputs.

; catch up on any incoming midi data
		pagesel	process_inbound_midi
		call	process_inbound_midi
		pagesel	poll
; Update LED States
		pagesel	update_leds
		btfss	STATE_FLAGS,1
		call	update_leds
		pagesel	poll

; catch up on any incoming midi data
		pagesel	process_inbound_midi
		call	process_inbound_midi
		pagesel	poll
; process analog inputs
		btfss	STATE_FLAGS,1
		call	read_analog_inputs

; catch up on any incoming midi data
		pagesel	process_inbound_midi
		call	process_inbound_midi
		pagesel	poll
; process digital inputs
		btfss	STATE_FLAGS,1
		call	read_logic_inputs

; catch up on any incoming midi data
		pagesel	process_inbound_midi
		call	process_inbound_midi
		pagesel	poll
; process matrixed inputs
		btfss	STATE_FLAGS,1
		call	read_matrices

		goto	poll

		end

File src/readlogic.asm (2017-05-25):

; MIDI CPU
; copyright John Staskevich, 2017
; john@codeandcopper.com
;
; This work is licensed under a Creative Commons Attribution 4.0 International License.
; http://creativecommons.org/licenses/by/4.0/
;
; readlogic.asm
;
; Take samples from pins configured for logic input.
;
		list		p=16f887
   		#include	<p16f887.inc>

   		#include	<mc.inc>



; ==================================================================
;
; External Functions
;
; ==================================================================

		EXTERN	inbound_sysex_finish
		EXTERN	process_inbound_midi
		EXTERN	main_init
		EXTERN	read_pin_config
		EXTERN	combine_channel_with_status
		EXTERN	load_d0_from_address
		EXTERN	load_d1_from_address
		EXTERN	add_to_d0_from_d1_address
		EXTERN	point_to_d0_address
		EXTERN	send_midi_byte
		EXTERN	send_midi_local

; ==================================================================
;
; Global Functions
;
; ==================================================================

		GLOBAL	read_logic_inputs


read_logic		code	0x0A60
;read_logic		code


read_logic_inputs
; no interference yet
		bcf		STATE_FLAGS,2
; Pins 0-7
		clrf	OUTPUT_COUNTER
; store the input states to TEMP
		movfw	PORTD
		movwf	TEMP
		movwf	TEMP4
; store the change flags to TEMP2
		xorwf	DIGITAL_0,w
		movwf	TEMP2
; update the toggles, copy to TEMP3
		comf	TEMP,w
		andwf	TEMP2,w
		banksel	LOGIC_TOGGLES_0
		xorwf	LOGIC_TOGGLES_0,w
		movwf	LOGIC_TOGGLES_0
;		banksel	PORTA
		movwf	TEMP3
; process the trigger inputs
		call	read_trigger_byte
; bail out if relevant sysex message comes in.
		btfsc	STATE_FLAGS,2
		return
; process the encoder inputs
		clrf	OUTPUT_COUNTER
		movfw	TEMP4
		movwf	TEMP
		xorwf	DIGITAL_0,w
		movwf	TEMP2
		movfw	DIGITAL_0
		movwf	TEMP3
		movlw	ENCODER_0
		movwf	ANALOG_INPUT
; for continuous note stuff
		movlw	ENCODER_CN_GATES_0
		movwf	TEMP_REG
		call	read_encoder_byte
; save the new input states
		movfw	TEMP4
		movwf	DIGITAL_0


;		return


; Pins 8-15
		movlw	D'8'
		movwf	OUTPUT_COUNTER
; store the input states to TEMP
		movfw	PORTB
		movwf	TEMP
		movwf	TEMP4
; store the change flags to TEMP2
		xorwf	DIGITAL_1,w
		movwf	TEMP2
; update the toggles, copy to TEMP3
		comf	TEMP,w
		andwf	TEMP2,w
		banksel	LOGIC_TOGGLES_1
		xorwf	LOGIC_TOGGLES_1,w
		movwf	LOGIC_TOGGLES_1
;		banksel	PORTA
		movwf	TEMP3
; process the trigger inputs
		call	read_trigger_byte
; bail out if relevant sysex message comes in.
		btfsc	STATE_FLAGS,2
		return
; process the encoder inputs
		movlw	D'8'
		movwf	OUTPUT_COUNTER
		movfw	TEMP4
		movwf	TEMP
		xorwf	DIGITAL_1,w
		movwf	TEMP2
		movfw	DIGITAL_1
		movwf	TEMP3
		movlw	ENCODER_4
		movwf	ANALOG_INPUT
; for continuous note stuff
		movlw	ENCODER_CN_GATES_1
		movwf	TEMP_REG
		call	read_encoder_byte
; save the new input states
		movfw	TEMP4
		movwf	DIGITAL_1


; Pins 16-23
		movlw	D'16'
		movwf	OUTPUT_COUNTER
; store the input states to TEMP
		movfw	PORTA
		movwf	TEMP2

		andlw	B'00001111'
		movwf	TEMP

		btfsc	TEMP2,5
		bsf		TEMP,4

		movfw	PORTE
		movwf	TEMP2
		rlf		TEMP2,f
		rlf		TEMP2,f
		rlf		TEMP2,f
		rlf		TEMP2,f
		rlf		TEMP2,f
		movfw	TEMP2
		andlw	B'11100000'
		iorwf	TEMP,f
		movfw	TEMP
		movwf	TEMP4
; store the change flags to TEMP2
		movfw	DIGITAL_2
		xorwf	TEMP,w
		movwf	TEMP2
; update the toggles, copy to TEMP3
		comf	TEMP,w
		andwf	TEMP2,w
		banksel	LOGIC_TOGGLES_2
		xorwf	LOGIC_TOGGLES_2,w
		movwf	LOGIC_TOGGLES_2
;		banksel	PORTA
		movwf	TEMP3
; process the trigger inputs
		call	read_trigger_byte
; bail out if relevant sysex message comes in.
		btfsc	STATE_FLAGS,2
		return
; process the encoder inputs
		movlw	D'16'
		movwf	OUTPUT_COUNTER
		movfw	TEMP4
		movwf	TEMP
		xorwf	DIGITAL_2,w
		movwf	TEMP2
		movfw	DIGITAL_2
		movwf	TEMP3
		movlw	ENCODER_8
		movwf	ANALOG_INPUT
; for continuous note stuff
		movlw	ENCODER_CN_GATES_2
		movwf	TEMP_REG
		call	read_encoder_byte
; save the new input states
		movfw	TEMP4
		movwf	DIGITAL_2

		return

; =================================
;
; handle changes to block of 8 digital inputs
; input variables (munged):
;   TEMP: new input states
;   TEMP2: changed bit flags
;	TEMP3: toggle states
;   OUTPUT_COUNTER: first output number
;
; =================================
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

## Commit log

2017-05-26 added CircuitHub link to readme
2017-06-01 added PCB design, hex files, user manual
    [MIDI-CPU-Rev-N.brd, MIDI-CPU-worksheet.ods]
2017-06-16 added BOM
    [MIDI-CPU-Rev-N-BOM.xls, MIDI-CPU-Rev-N.brd]
2017-06-21 Programming cradle PCB design added.
    [MIDI-CPU-cradle.brd]
